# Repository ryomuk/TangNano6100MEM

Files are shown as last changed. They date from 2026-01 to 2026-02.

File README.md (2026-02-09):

# TangNano6100MEM
Memory systems and peripherals implemented on Tang Nano 20K for Intersil IM6100 PDP-8 Processor

This document is written mostly in Japanese, so please use machine translation if necessary.

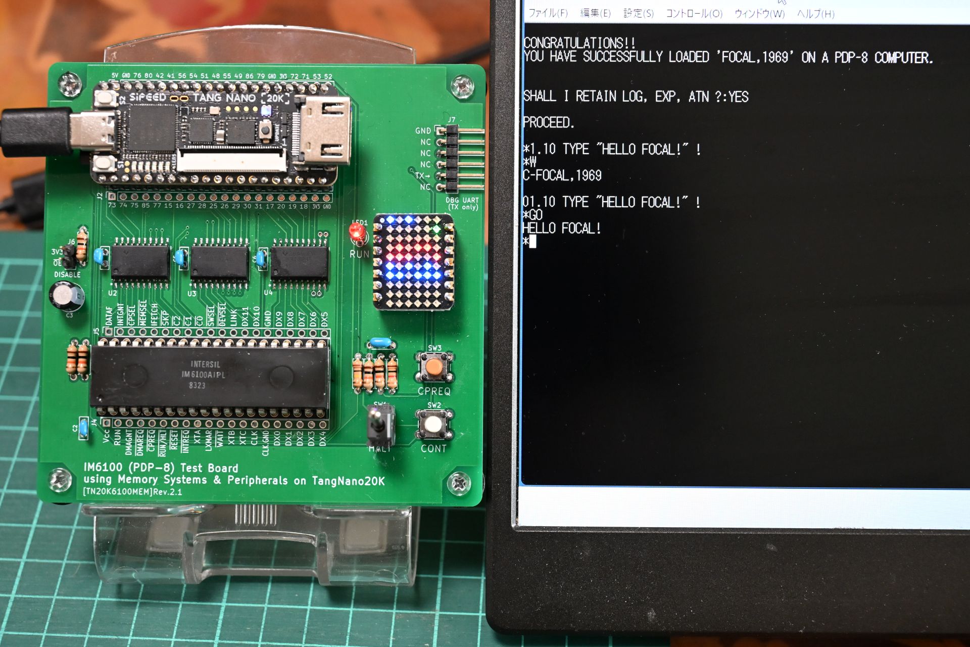
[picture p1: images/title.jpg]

# 概要
- PDP-8の命令セットを持つCPU「Intersil IM6100」のメモリシステムと周辺回路をFPGA(TangNano20K)上に実装する試みです．
- FPGAに実装するのはメモリ，UART, HDDなどの周辺装置の部分だけで，CPU自体は本物を使用します．ソフトウェアやFPGAによるシミュレータやエミュレータではなく，実物のCPUを動かします．
- "TangNano6100"だとTangNano上にIM6100を実装したみたいな名前になってしまうので，"MEM"を付けて"TangNano6100MEM"という名前になっています．
- モニタプログラムとして，Haruo Asano氏による[Universal Monitor](https://electrelic.com/electrelic/node/1317)IM6100版をControl Panel空間で動くように改変したものを搭載しました．MITライセンスだったので，使用した部分のソースを同梱しています．

## 最近の主な話題
- 2026/01/28: 初版公開
- 2026/02/01: version 20260201, 紙テープエミュレータ実装
- 2026/02/02: version 20260202, 割り込み関連のバグ修正
- 2026/02/02: CP空間のuniversal monitorにコンテキストの保存復帰を実装しました．
- 2026/02/06: version 20260206, 拡張メモリ関連の微修正
- 2026/02/06: OS/8のRK2, RK3を有効化する方法についてのドキュメントを追加．
  
## 主なファイル一覧
```
.
├── doc                      : 説明用文書
├── hdl                      : Gowin EDA用プロジェクト
│   ├── old                 : 旧版のバックアップ(あれば)
│   └── TangNano6100MEM_project: HDLソース一式
│       └── src
│            ├── dbglog.v   : debug log用モジュール
│            ├── mem.v      : メモリ初期データ(OS/8 bootloader)
│            ├── mem_cp.v   : CPメモリデータ(unimon)
│            ├── sdhd.v     : HDエミュレータモジュール
│            ├── sdtape.v   : 紙tapeエミュレータモジュール
│            ├── switch.v   : スイッチ用モジュール
│            ├── TangNano6100MEM_project.sdc : 時間制約(適当)
│            ├── tn20k.cst  :  物理制約(ピンアサイン)
│            ├── top.v      : メインプログラム
│            ├── uart.v     : uartモジュール
│            ├── ws2812.v   : WS2812モジュール
│            └── ws2812_matrix.v : WS2812 matrix用モジュール
├── images                   : 文書用画像ファイル
├── LICENSE
├── pcb
│   └── rev2.1 :  回路図，基板データ等(KiCAD 9用)
├── README.md   : このファイル
└── tools
    ├── papertape
    │   └── ptp2v.c    : 紙テープバイナリ変換用ソフト
    ├── sample          : bootやテスト用プログラム(unimonで書く用)
    └── unimon          : Universal Monitor
        ├── im6100      : IM6100 Control Panel版
        └── LICENSE.txt : 上記のライセンスファイル

```

各種説明は[doc/](./doc/)に項目に分けて記載しています．
- [更新履歴](doc/01_updatelog.md)
- [基板関連](doc/02_PCB.md)
- [FPGA関連](doc/03_FPGA.md)
- [インターフェース](doc/04_Interface.md)
- [SDメモリ](doc/05_SDmemory.md)
- [応用例](doc/06-0_applications.md)
  - [ベアメタル](doc/06-1_baremetal.md)
  - [紙テープソフト](doc/06-2_papertape.md)
  - [OS/8](doc/06-3_os8.md)
    - [RK2-3diskの有効化](doc/06-3_os8_reconfig.md)
- [デバッグツール](doc/07_debugtool.md)
- [関連情報・参考資料](doc/08_references.md)

## その他
以下，雑多な情報です．

### 動作状況
- 紙テープソフトやOS/8およびOS/8上で動く言語処理系などがある程度動作します．
- OS/8のBASICで簡単なプログラムを入力したりセーブ/ロードしたりできます．
  - STRTRK.BAやSNOOPY.BAが動きました．
- コントロールパネル空間でUniversal Monitorが動きます．

### 既知の問題
- ステップ実行後に戻ってくるとおかしくなることがある．
- ~~OS/8版のFOCALが動かない．おそらく割り込み関連の問題．~~ → やはり割り込みの問題でした．20260202版で修正して解決．
- ~~OS/8でDIR SYS: はできるが DIR RKA0: は止まる．~~ → PDP/8ハンドブックの誤植が原因でした．RK_DONEフラグを修正したら動くようになりました．
- ~~OS/8 BASICでSTRTRK.BAやSNOOPY.BAが動かない．~~ 動きました．

### 今後の予定，ToDo
- 紙テープイメージからOS/8のディスクイメージを作成．
  - → ある程度はできたのですが，CCL.SVがうまく作れなかったりEPICの動作が不安定なのであきらめました．
- 磁気テープドライブエミュレータ実装．(紙テープは実装済なので，必要でなければやらないかも)
  - → いろいろ面倒な仕様があったのであきらめました．

<!--
# 動画
- 未
-->

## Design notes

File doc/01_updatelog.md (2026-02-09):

# 更新ログ
- 2026/01/28: 初版公開
  - PCB rev2.1
  - HDL version 20260128
- 2026/01/29: HDLアップデート(version 20260129)
  - ステータスレジスタのフラグ(RK_DONE)修正
  - dbg_mode導入(SW2でクロック1000Hzにしてログ出力)
- 2026/02/01: HDLアップデート(version 20260201)
  - 紙テープエミュレータ実装
  - universal monitorにコマンド追加(Switch register, data field)
- 2026/02/02: HDLアップデート(version 20260202)
  - 割り込み時に拡張メモリのレジスタ(REG_IF, DF, IB)のクリアを追加
- 2026/02/02:
  - CP空間のuniversal monitorにコンテキストの保存復帰を実装しました．
- 2026/02/06:
  - CP空間ではJMP,JMS時にIF<=IBをしないように修正

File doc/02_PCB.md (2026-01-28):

# 基板 rev.2.1
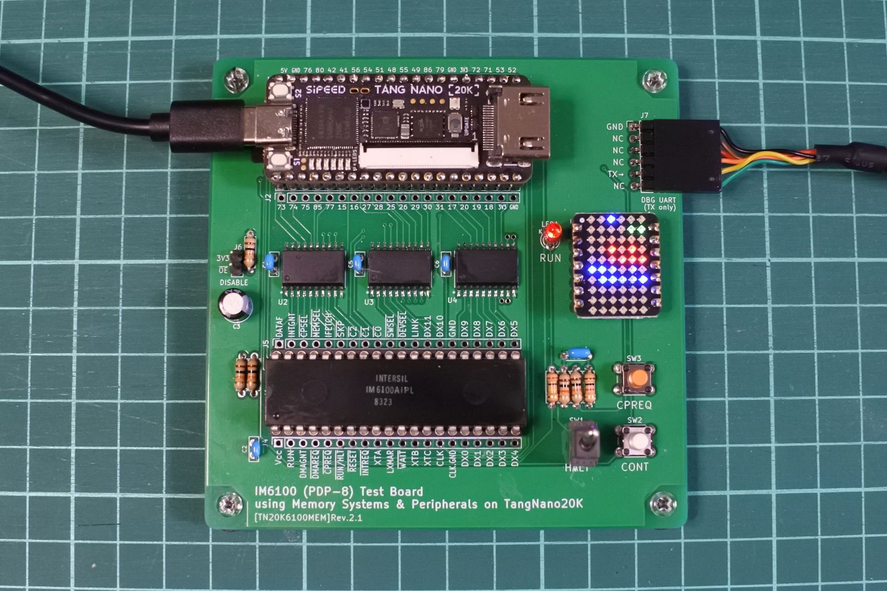
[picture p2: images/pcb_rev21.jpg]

#### BOM
|Reference |Value| Qty  |Memo |
|---|-----|---|-----|
|C1|1uF|1|||
|C2,C4,C5,C6|0.1uF|4||
|C3|47uF|1|||
|J1|01x20 pin socket|2|TangNano20K用|
|J2,J3,J4,J5|01x20 pin socket or header|4||実験用．無くても可．|
|J6|01x2 pin header|1|無くても可．|
|J7|01x6 pin header(L字)|1|デバッグUART用|
|LED1|LED|1| If=50μAぐらいで点灯するもの|
|R1,R2,R4,R5,R7|10k|5||
|R3|47k|1||
|R6|1k|1||
|SW1|トグルSW|1||
|SW2, SW3|タクトSW|1||
|U1|IM6100A|1|40P DIP 600mil socket|
|U2,U3,U4|SN74CB3T3245DWR(DWでも可)|3|SOIC-20．サイズに注意|
|U5|WS2812B 6x10 matrix|1|Seeed Studio XIAO用 6×10 RGBマトリクス|

#### パーツに関する補足や注意事項
- SN74CB3T3245はパッケージサイズに注意．SOIC-20はDWかDWRです．PWやPWRではありません．
- LEDは47KΩつけたけでCPUに直結しています．If=70μAぐらいで点灯するLEDを使って下さい．とりあえず，下記が使えることを確認しました．
  - OSR5PA3133A-1MA https://akizukidenshi.com/catalog/g/g116908/ 最初これを使っていたのですが販売終了でした．
  - OSR5JA3Z74A https://akizukidenshi.com/catalog/g/g111577/
  - OSR5JA7WA1B https://akizukidenshi.com/catalog/g/g114260/

#### 主なパーツの入手先
|parts |store|
|---|-----|
|Tang Nano 20K| 秋月, Sipeed Store(Aliexpress)|
|SN74CB3T3245DWR|マルツ, Mouser, Digikey|
|IM6100A|eBay|
|Seeed Studio XIAO用 6×10 RGBマトリクス|マルツ, Switch Science|
|その他の部品| 秋月, マルツ，共立|

#### レベル変換について
- 信号のインターフェース部分にはバススイッチSN74CB3T3245を使用しています．
  - CPU→FPGAの信号レベルは5Vから3.3Vに変換されます．
  - FPGA→CPUの信号レベルは3.3Vのままです．
- IM6100のデータシートによると，TTL compatibleとあるので3.3Vレベルの信号を入力に使えるはずなのですが，一方でVih=70%*Vcc との記載もあり，若干不安だったのですがとりあえず今の実装で動いているので大丈夫なようです．

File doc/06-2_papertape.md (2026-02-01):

# paper tape software
- SDメモリで動作する紙テープエミュレータを実装しました。
- インターネット上のPDP8関連のアーカイブから入手できる紙テープのイメージを全く加工せずにddで書き込むだけでロードと起動ができることを目標にしました．
- tangnanoのSW1で8個のtape imageから1つ選択します．
- 0が1024個続くとEnd of Tapeと判断し読み込みは停止します．状態はMatrix LEDに表示されます．(LEDの位置はtop.v参照．)
- モニタからGで起動したときや読み込みの途中でEOTでないのにHALTで止まったらCONTを押して継続します．

## boot loader
- RIM loader(開始アドレス=7756)をいちいちモニタで書き込むのは面倒なので，メモリ上に置いてあります．(当時はパネルスイッチでパチパチ入力していたようですが．)
- ついでにbinary loader(開始アドレス=7701)も置いておきましたが，ちょっとチートな気もします．binary loader自身もちゃんとRIM loaderで読む方が本格的な気分になれます．(mem.vのdefine文で無効にできます．)
- メモリの初期値は今後変わるかもしれないので，最新の情報はmem.vを確認して下さい．

## 動作例
### 4k BASIC (edusystem 10)
- http://www.bitsavers.org/bits/DEC/pdp8/papertapeImages/basic/edusystem-10/
- ファイル名: dec-08-ed10a-a-pb-new.ptp
- 最初にbinary loader，続いてプログラムが格納されている．
- RIMローダーを起動するだけで自動的に実行された．
```
Universal Monitor IM6100 (Control Panel)
7777
] G7756
# HALTで止まっていたらCONTボタンを押す

SELECT THE SMALLEST SET OF FUNCTIONS NEEDED FROM THE FOLLOWING CHOICES
ATN         ! !X! ! ! ! ! !
LOG+EXP     ! !X!X! ! ! ! !
SIN+COS+TAN ! !X!X!X! ! ! !
DEF(FN)     ! !X!X!X!X! ! !
SQR         ! !X!X!X!X!X! !
RND         ! !X!X!X!X!X!X!

OPTION       A B C D E F G

TYPE OPTION LETTER?G
DO SUBSCRIPTS START AT 0 OR 1?0
READY.
```

### 8k BASIC
- https://computermuseum.informatik.uni-stuttgart.de/ftp/dec/papertapes/basic-8/
- ファイル名: BASIC8.BN
- 上記リンクにソースとマニュアルもあり．
- binary loaderでロード
- 開始アドレス=1000
```
Universal Monitor IM6100 (Control Panel)
7777
] G7701
# HALTで止まったらCONTを押す．
# End of TapeになったらCPREQでモニタを起動
Universal Monitor IM6100 (Control Panel)
7670
] G1000

READY.

PRINT "HELLO 8K BASIC"
HELLO 8K BASIC
```

### FOCAL
- http://www.bitsavers.org/bits/DEC/pdp8/From_pdp8.hachti.de/hachti-pdp8-tapes/
- ファイル名: DEC-08-AJAE-PB.bin
- 開始アドレス=0200
- binary loaderで起動します．
- 末尾のゴミ(後述)のせいでDFが1になったり，244番地が書き替えられてたりするので手動で修正します．
```
Universal Monitor IM6100 (Control Panel)
7777
] G7701
# 途中で5〜6回くらい止まるのでCONTで読込を継続．
# End of TapeになったらCPREQでモニタに戻ってDFと244番地を修正して起動．

Universal Monitor IM6100 (Control Panel)
7671
] F0
0000
] S244
0244 : 3044 4554
0245 : 1124 .
] G200

CONGRATULATIONS!!
YOU HAVE SUCCESSFULLY LOADED 'FOCAL,1969' ON A PDP-8 COMPUTER.

SHALL I RETAIN LOG, EXP, ATN ?:YES

PROCEED.

*1.10 TYPE "HELLO FOCAL!" !
*W
C-FOCAL,1969

01.10 TYPE "HELLO FOCAL!" !
*GO
HELLO FOCAL!
*

```
末尾のこのあたりのデータが悪さをしているようです．削除してもいいのですが，上記修正で直ったのでとりあえずそれで済ませました．
```
# /usr/bin/od -t o1 DEC-08-AJAE-PB.bin | less
0017600 000 000 000 000 000 000 000 000 000 000 000 252 125 252 056 073
0017620 052 056 000 000 000 000 000 000 000 000 000 000 000 000 000 000
0017640 000 000 000 000 000 000 000 000 000 000 000 000 000 000 000 000
*
0020100 000 000 000 000 000 000 102 044 030 044 102 201 102 044 030 044
0020120 102 201 102 044 030 044 102 201 314 000 000
```

### LISP
- http://www.bitsavers.org/bits/DEC/pdp8/papertapeImages/set1/
- ファイル名: DECUS_8_102A_LISP.BIN
- 開始アドレス=3000 (自動実行)
- 自動実行なので，Self-Starting Binary Loader を試してみました．
  - https://deramp.com/downloads/mfe_archive/011-Digital%20Equipment%20Corporation/01%20DEC%20PDP-8%20Family%20Software/02%20Paper%20Tape%20Utilities/DEC-8E-XBINA%20Bina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
  - ファイル名: DEC_8E_XBINA_A_PB.BIN

```
# G7756でRIM Loaderを起動してSS Bin Loaderを読む．
Universal Monitor IM6100 (Control Panel)
7777
] G7756
# EOTが点灯して止まったら，SW1でイメージファイルをLISPに変更してCONT
# 再度EOTが点灯するまで5回くらいCONT
# EOTの点灯と同時にLISPが起動する．(起動メッセージは無い)

()()
 NIL
CAR((A B C))
 A

```

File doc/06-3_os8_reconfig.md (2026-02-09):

## RK2, RK3 diskの有効化

- os8.rk05は，RKのunitが2台((RKA0, RKB0)と(RKA1, RKB1))の設定でBUILDされている
ようなので設定を変更します．手順は下記の通り．

- モニタからOS/8を起動します．
```
Universal Monitor IM6100 (Control Panel)
07777
AC=0000 FLG,IF,DF=0000 SR=0000
] G23
```
- 登録されているデバイス(リソース)を確認します
```
.RES /L

1109 FREE BLOCKS

 NAME TYPE USER
 SYS  RK8E
 DSK  RK8E
 PTP  PTP 
 PTR  PTR 
 RXA0 RX8E
 RXA1 RX8E
 RKA0 RK8E
 RKB0 RK8E
 RKA1 RK8E
 RKB1 RK8E
 TTY  TTY 
 LPT  LPTR
 RF   RF08
 DTA0 TC08
 DTA1 TC08

OS/8 V3Q
```
- まだRKB3:は無いので下記はエラーになります．
```
.DIR RKB3:
RKB3 DOES NOT EXIST
```
- BUILDを起動します．
```
.R BUILD
```
- 登録されているデバイスを確認します．有効なデバイスにはアスタリスクが付いています．RKA2-3, RKB2-3はハンドラはあるようですが有効化されていません．
```
$PR

PT8E: *PTP  *PTR  
RX01: *RXA0 *RXA1 
RK8E: *SYS   RKA0  RKB0 
RK05: *RKA0 *RKB0 *RKA1 *RKB1  RKA2  RKB2  RKA3  RKB3 
KL8E: *TTY  
LS8E: *LPT  
RF  : *RF    NULL 
TC  : *DTA0 *DTA1  DTA2  DTA3  DTA4  DTA5  DTA6  DTA7 
```
- 全部で16個までしか登録できないので，いらないデバイスを削除します．
```
$UNLOAD RX01

$UNLOAD RF

$UNLOAD TC
```
- RK2(RKA2, RKB2)とRK3(RKB2, RKB3)を有効化します．
```
$IN RK05:RKA2-3,RKB2-3
```
- 確認します．
```
$PR

PT8E: *PTP  *PTR  
RK8E: *SYS   RKA0  RKB0 
RK05: *RKA0 *RKB0 *RKA1 *RKB1 *RKA2 *RKB2 *RKA3 *RKB3 
KL8E: *TTY  
LS8E: *LPT  
```
- BOOTします．
```
$BOOT
SYS BUILT
```
- リソースを確認します．
```
.RES /L

1109 FREE BLOCKS

 NAME TYPE USER
 SYS  RK8E
 DSK  RK8E
 PTP  PTP 
 PTR  PTR 
 RKA0 RK8E
 RKB0 RK8E
 RKA1 RK8E
 RKB1 RK8E
 RKA2 RK8E
 RKB2 RK8E
 RKA3 RK8E
 RKB3 RK8E
 TTY  TTY 
 LPT  LPTR

OS/8 V3Q
```
-  ディスクアクセスのログによると，BOOT時にSYS:上のファイルが書き換えられているようでした．rebootして確認します．
```
.
Universal Monitor IM6100 (Control Panel)
01210
AC=0000 FLG,IF,DF=4000 SR=0000
] S23
0023 : 0200 6007
0024 : 1200 6744
0025 : 0211 1032
0026 : 7607 6746
0027 : 5372 6743
0030 : 6203 1032
0031 : 0321 5031
0032 : 1630 0000
0033 : 0402 .
] G23

.RES /L

1109 FREE BLOCKS

 NAME TYPE USER
 SYS  RK8E
 DSK  RK8E
 PTP  PTP 
 PTR  PTR 
 RKA0 RK8E
 RKB0 RK8E
 RKA1 RK8E
 RKB1 RK8E
 RKA2 RK8E
 RKB2 RK8E
 RKA3 RK8E
 RKB3 RK8E
 TTY  TTY 
 LPT  LPTR

OS/8 V3Q
```
- RKB3:が読めるようになりました．
```
.DIR RKB3:

ABSLDR.SV   6           RL2SY .BH   2           DHLAAB.DG  13
CCL   .SV  31           RL20  .BH   2           DHTAAC.DG  17
DIRECT.SV   7           RL21  .BH   2           DHTABC.DG  13
PIP   .SV  11           RL2E  .BH   2           DHTMAB.DG  17
FOTP  .SV   8           ROMMSY.BH   1           DHTMBB.DG  17
SET   .SV  20           RXSY1 .BH   2           DHTMCA.DG  10
FUTIL .SV  27           RXSY2 .BH   2           DHTMDB.DG  15
BATCH .SV  10           RXNS  .BH   2           DHTMEB.DG  15
HELP  .SV   8           RXBSY1.BH   2           DHTMFC.DG  11
FRTS  .SV  26           RXBSY2.BH   2           DHTSAB.DG  17
RKBOOT.SV   2           RXBNS .BH   2           DHTSBB.DG  17
BASIC .SV  11           RX28C .BH   2           DHTSCB.DG  15
BLOAD .SV  10           RX78C .BH   2           DHTSDB.DG  13
BCOMP .SV  26           TC08SY.BH   1           DHTSEA.DG  10
BRTS  .SV  25           TC08NS.BH   2           DHTSFA.DG   3
CHESS .SV  28           TD8ESY.BH   2           DHVCAA.DG  13
ADVENT.SV 129           TD8EA .BH   2           DHVTAB.DG  11
BASIC .UF   2           TD8EB .BH   2           DHVTBA.DG   4
BASIC .OV  16           TM8E  .BH   2           DHVTDA.DG  16
RK8EA .SY  50           VXSY  .BH   1           DIADFA.DG  11
RK8EB .SY  50           VXNS  .BH   1           DIAFBA.DG  17
RKS8EA.SY  50           RECOVR.BI   2           DIDBAA.DG   7
RKS8EB.SY  50           ADVENT.DA 145           DIDFAC.DG   7
HELP  .HL  67           ADVENT.LD 143           DIDFBA.DG  10
GAMES .HL  63           ADVENT.TX 200           DIDFCA.DG  17
ASR33 .BH   1           BANNER.BA  23           DILTCA.DG   6
BAT   .BH   1           FUTIL .TX 316           DILTDA.DG  10
CR8E  .BH   2           DECX8 .TX  64           DILVAA.DG  10
CS    .BH   2           OS8   .TX  58           DIRTAB.DG  14
DF32SY.BH   1           DIAG  .TX  88           DITCBA.DG  11
DF32NS.BH   1           TITLE .TX   7           DITCCA.DG   9
DUMP  .BH   2           TYPSET.DG  10           DITCDA.DG  15
KL8E  .BH   2           SHELLY.DG   4           DIUDAC.DG  17
LINCSY.BH   1           AUVAAA.DG  16           DIVTBA.DG   8
LINCNS.BH   2           AUVBAB.DG  16           DIVTCA.DG  11
LPSV  .BH   1           AUVCAA.DG   6           DJADAC.DG  16
LQP   .BH   2           AUVDAB.DG   9           DJVKAB.DG  15
MODLQP.BH   2           AUVEAD.DG   8           DIRECT.TS   6
PT8E  .BH   1           DGV5AB.DG  13           RKS8ES.PA  37
RF08SY.BH   1           DHADAA.DG  11           RKSFMT.LC   6
RF08NS.BH   1           DHCMAA.DG  10           RKSREL.LC   9
RK08SY.BH   1           DHCRAA.DG  10           RKSLES.LC  16
RK08NS.BH   1           DHDHAA.DG   7           RKSWCT.LC   8
RK8EA .BH   1           DHDHCA.DG   2           RKSCTL.LC  16
RK8EB .BH   1           DHDKAA.DG  15           RKCOPY.LC   5
RK8ENS.BH   2           DHDPAD.DG  18           JDAY8E.SY  50
RKS8EA.BH   1           DHDRAB.DG  11           RKSFMT.DG   6
RKS8EB.BH   1           DHDRHA.DG  11           RKSWCT.DG   8
RKS8NS.BH   2           DHICAA.DG  21           RKSCTL.DG  16
RLSY  .BH   2           DHKGAB.DG  14           RKSREL.DG   9
RL0   .BH   2           DHKLBB.DG  13           RKSLES.DG  16
RL1   .BH   2           DHKLCD.DG   8           RKCOPY.DG   5
RLC   .BH   2           

 157 FILES IN 2762 BLOCKS -  430 FREE BLOCKS

.

```

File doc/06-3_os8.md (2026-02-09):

## OS/8
- 下記のdisk imageで起動できました．
- [CPLDP-8 by omiokone](https://omiokone.sakura.ne.jp/cpldp8/index.htm) cpld83C.zip中にある os8.rk05
- [pdp8online:PDP-8 File list for os8](https://www.pdp8online.com/images/images/os8.shtml) にある，advent.rk05 , diag-games-kermit.rk05, diagpack2.rk05
を8192ブロックごとに並べたファイルsd.dskを作り，ddでSDメモリの先頭ブロックから書き込みます．
```
dd if=os8.rk05               of=sd.dsk bs=512
dd if=advent.rk05            of=sd.dsk bs=512 seek=8192  conv=notrunc
dd if=diag-games-kermit.rk05 of=sd.dsk bs=512 seek=16384 conv=notrunc
dd if=diagpack2.rk05         of=sd.dsk bs=512 seek=24576 conv=notrunc

dd if=sd.dsk of=/dev/xxx
```
/dev/xxx は/dev/sdbなど，生のsdメモリの場所です．ちゃんと調べて間違えないように書き込んで下さい．間違えるとPCのディスクを破壊する可能性があります．

### 起動方法
- SDメモリをTangConsoleのスロットにセットします．
- コントロールパネルのUniversal Monitorを起動します．

### 使用例
下記のようにメインメモリ空間にOS/8のboot loaderを書いて実行することによりbootできます．

```
Universal Monitor IM6100 (Control Panel)
7777
] S23
0023 : 0005 6007
0024 : 3602 6744
0025 : 0000 1032
0026 : 3724 6746
0027 : 0000 6743
0030 : 7500 1032
0031 : 0000 5031
0032 : 0001 0000
0033 : 0000 .
] G23

.DIR

ABSLDR.SV   5           BASIC .FF   4           PAGE8 .SV  49
BATCH .SV  10           BASIC .SF   4           ICE   .SV  26
...(略)...
LOADER.SV  12           LISP  .SV  18           HOGE  .BA   1
SABR  .SV  24           PASCAL.SV  51           BASIC .WS   1
BASIC .AF   4

  94 FILES IN 2085 BLOCKS - 1107 FREE BLOCKS

.
```

- os8.rk05は，RKのunitが2台((RKA0, RKB0)と(RKA1, RKB1))の設定でBUILDされているようなので設定を変更します．手順は[06-3_os8_reconfig](./06-3_os8_reconfig.md)参照．

- BASICで簡単なプログラムを入力したりセーブ/ロードしたりできました．

```
.R BASIC
NEW OR OLD--NEW
FILE NAME--AAA

READY
10 PRINT "HELLO OS/8 BASIC"
20 END
LIST

AAA     BA    5B

10 PRINT "HELLO OS/8 BASIC"
20 END

READY
RUN

AAA     BA    5B

HELLO OS/8 BASIC

READY
SAVE

READY
BYE

.R BASIC
NEW OR OLD--OLD
FILE NAME--AAA

READY
LIST

AAA     BA    5B

10 PRINT "HELLO OS/8 BASIC"
20 END

READY
```

- STRTRK.BAも動きました．
```
.BASIC
NEW OR OLD--OLD
FILE NAME--STRTRK

READY
RUN

STRTRK  BA    5B

STAR TREK SPACE SIMULATOR

DO YOU NEED INSTRUCTIONS?N

COMBAT AREA   CONDITION RED
  SHIELDS DANGEROUSLY LOW

------------------------

    *                        STARDATE      3400
                             CONDITION     RED
         +++                 ENERGY        3000
                             TORPEDOES     15
                      *      SHIELDS       0
      +++                    KLINGONS      21
 *     *  *          <*>
------------------------
COMMAND?
```

- FOCALも動きました．
```
.R PFOCAL

DO YOU WANT THE STANDARD FEATURES OF PS/8 FOCAL, 1971?  NO

RETRY OR TYPE HELP:  HELP

ANSWER BY TYPING THE CODES TO RETAIN THE FEATURES:

1  SIN & COS
2  SIN, COS, LOG, EXP & ATN
3  EXTENDED PRECISION
4  FILE COMMANDS
5  LEADING SPACE IN 'TYPE'
6  '=' IN 'TYPE' (OPTION 5 DISABLES THIS OPTION)
7  ':' IN 'ASK'
8  '&' IN POWERS-OF-TEN NOTATION
9  RETAINS FEATURES 2,3,4
0  RETAINS NONE OF LISTED FEATURES

YES  RETAINS STANDARD FEATURES 2,3,4,5
RUBOUT DELETES PRECEEDING CHARACTER
'_' OR CTRL/U KILLS LINE

DO YOU WANT THE STANDARD FEATURES OF PS/8 FOCAL, 1971?  0

PROCEED.

*1.10 TYPE "HELLO OS/8 FOCAL!" !
*W
C-PS/8 FOCAL, 1971

01.10 TYPE "HELLO OS/8 FOCAL!" !
*GO
HELLO OS/8 FOCAL!
*
```

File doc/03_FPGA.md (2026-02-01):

# FPGA関連
## ビルド時の注意点
### Gowin FPGA Designerの設定について
- Configulationはimpl/の*.config.jsonに保存されているようなので，特に何もする必要は無いはずですが，もしエラーが出た場合は、Configuration->Dual-Purpose Pin で"Use SSPI as regular IO"をチェックして下さい．
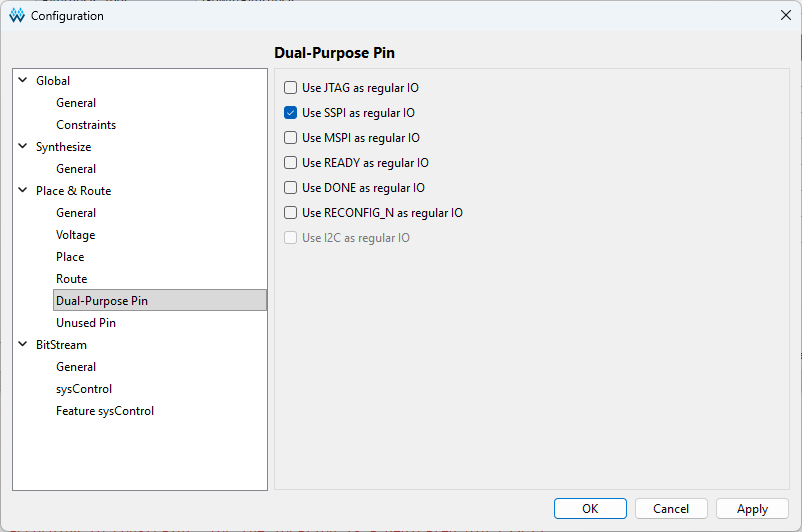
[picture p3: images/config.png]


### warning
- 下記のwarningが出ますが，対処方法がいまいちわからないので放置しています．
```
WARN  (PR1014) : Generic routing resource will be used to clock signal 'sys_clk27_d' by the specified constraint. And then it may lead to the excessive delay or skew
```

### program
- UARTのポートが複数あるので，Gowin programmerでは適切なポートを選択する必要があります．
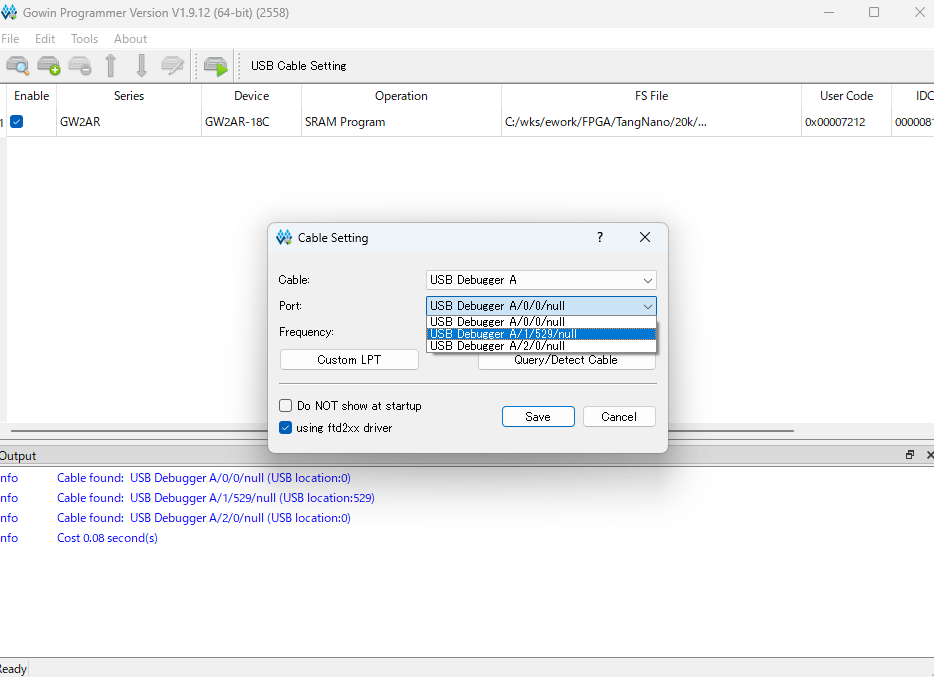
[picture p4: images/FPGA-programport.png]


# FPGAに実装した機能
- TTYコンソール入出力用UART
- 32MW メモリシステム(拡張メモリ)
- 4KW コントロールパネルメモリ
- 割り込み
- RK8E/RK05 ハードディスク (sdメモリによるエミュレーション)
- デバッグ機能(デバッグログ，matrix LED, debug用HALT, CP空間モニタ)

## デバッグ用機能
- 6x10 matrixにいろいろな情報が出力されます．詳細はソースtop.vを参照．
- DBG_UARTに下記の情報が出力されます．詳細はソースtop.vを参照．
  - 一番左は1msタイマーの値．
  - RKディスクアクセス時のコマンド，ディスクアドレス，メモリアドレス等
  - ステップ実行時の命令，アドレス等
- CPREQ ボタンを押すとControl Panel空間でUniversal Monitorが起動します．

## CPUのクロックについて
- CPUのクロックはTangNanoの27MHzのsys_clkを分周して作っています．PLLを使えばもっと細かい値の制御ができますが，IPはなるべく使わない方針なので．
- 分周比が奇数のときはduty比が50%より若干大きくなります．50%にしたら5.4MHzで動かなくなったので，50%にするためのコードはコメントアウトしてます．なので分周比は偶数の方が安全かと思います．
- IM6100AはVcc=10Vで8MHzというスペックのようですが，5Vでも5.4MHzであれば動き，個体によっては6.75MHzで動作するものもありました．ただ，4.5MHzでも時々誤動作することがあったので，余裕をみて3.375MHzにしています．
- もっと速いクロックを試す場合や，6100無印, -1, C等を使う場合には必要に応じてtop.vのCPU_CLK_RATIOを変更して下さい．

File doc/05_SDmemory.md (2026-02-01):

## SDメモリ
- RKディスクエミュレータと紙テープエミュレータ用のディスクイメージをSDメモリに書き込み，TangNano 20KのSDメモリスロットに入れます．
- fat等のファイルシステムは持たず，ddでブロックの先頭から生で使用します．

## メモリイメージの構成
- まだ開発途上なので変更する可能性があります．
- 基本的にはtop.vのコメントに書いてあります．下記に再掲します．
- SW1で先頭ブロックをシフトして紙テープイメージを選択できるようになっています．

```
// RK Disk
// 256 word x 16 sector x 203 cyl(track) x 2 surface
// 6496 * 256word(512byte) block (1,662,976 word)
//
// 1 block = 256word = 512B = 01000B
// SD memory block
// each RK05 disk image uses first 6496 block in 8192 block.
// (DRIVE_BLOCK_SIZE = 8192 (= 16 * 2 * 256))
//        0- 8191: RK0 (00000000)
//     8192-16383: RK1 (00020000)
//    16384-24575: RK2 (00040000)
//    24576-32767: RK3 (00060000)
//    32768-33791: TP0 (00100000)
//    33792-34815: TP1 (00102000)
//    34816-35839: TP2 (00104000)
//    35840-36863: TP3 (00106000)
//    36864-37887: TP4 (00110000)
//    37888-38911: TP5 (00112000)
//    38912-39935: TP6 (00114000)
//    39936-40959: TP7 (00116000)
//
```

複数のディスクイメージをまとめてsdメモリ用のイメージsd.dskを作る例．

```
# disk images
dd if=os8.rk05                  of=sd.dsk bs=512
dd if=diag-games-kermit.rk05    of=sd.dsk bs=512 seek=8192  conv=notrunc
dd if=advent.rk05               of=sd.dsk bs=512 seek=16384 conv=notrunc
dd if=sample.rk05               of=sd.dsk bs=512 seek=24576 conv=notrunc
# tape images
dd if=dec-08-lbaa-pm            of=sd.dsk bs=512 seek=32768 conv=notrunc
dd if=DEC_8E_XBINA_A_PB.BIN     of=sd.dsk bs=512 seek=33792 conv=notrunc
dd if=dec-08-ed10a-a-pb-new.ptp of=sd.dsk bs=512 seek=34816 conv=notrunc
dd if=BASIC8.BN                 of=sd.dsk bs=512 seek=35840 conv=notrunc
dd if=DEC-08-AJAE-PB.bin        of=sd.dsk bs=512 seek=36864 conv=notrunc
dd if=DECUS_8_102A_LISP.BIN     of=sd.dsk bs=512 seek=37888 conv=notrunc
```

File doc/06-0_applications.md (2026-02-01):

# 応用例

## [ベアメタル](06-1_baremetal.md)
## [Paper Tape Software](06-2_papertape.md)
## [OS/8](06-3_os8.md)

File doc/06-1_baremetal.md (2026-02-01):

# ベアメタル

下記のような手段でプログラムをメモリに格納し，ベアメタルで動作させることができます．
- universal monitor(使い方は[debugtool.md](07_debugtool.md)参照)でメモリに書く
- アセンブラで作成したバイナリデータやmem.vに変換してビルド
- 紙テープイメージから作ったメモリデータをmem.vに変換してビルド

### Universal Monitorでメモリに書いて実行
```
# CPREQボタンを押してモニタを起動
Universal Monitor IM6100 (Control Panel)
7777
] S200
0200 : 0000 6032
0201 : 0000 6031
0202 : 0000 5201
0203 : 0000 6036
0204 : 0000 6046
0205 : 0000 6041
0206 : 0000 5205
0207 : 0000 5200
0210 : 0000 .
] G200
# HALTで止まっていたらCONTボタンを押す
# キー入力がechoされる
Hello!
Keyboard echo test
```

### アセンブラで作ったバイナリからメモリデータへの変換
- [tools/unimon/im6100/bin2v.pl](../tools/unimon/im6100/bin2v.pl)
を参考にして下さい．コントロールパネル空間用になっているので，適宜変更して下さい．

### 紙テープイメージからメモリデータへの変換
- 紙テープエミュレータを実装する前は，紙テープのimageをFPGAの初期メモリデータmem.vに変換して再ビルドするという手順で紙テープソフトを実行しました．変換用のプログラムはこれ→[tools/papertape/ptp2v.c](../tools/papertape/ptp2v.c) 
- テープの末尾のゴミを手作業で修正する必要があります．(それほど多くはない)
- 起動アドレスを7776番地に書き込みます．(CPのunimonからGで実行しても可．)
- リセット時に7777でHALTするので，CONTボタンを押して実行．

#### FOCAL
```
$ ptp2v DEC-08-AJAE-PB.bin > mem.v
開始アドレスを修正 (そのままにしてCPのunimonからG200でも可)
mem['o7776]='o7777; // set start address here
↓
mem['o7776]='o0200;
```
ビルドしてFPGAに書き込んで起動．
```
CONGRATULATIONS!!
YOU HAVE SUCCESSFULLY LOADED 'FOCAL,1969' ON A PDP-8 COMPUTER.

SHALL I RETAIN LOG, EXP, ATN ?:YES

PROCEED.

*
```

#### 4K BASIC
```
$ ptp2v dec-08-ed10a-a-pb-new.ptp > mem.v
開始アドレスを修正
mem['o7776]='o7777; // set start address here
↓
mem['o7776]='o0200;
```
ビルドしてFPGAに書き込んで起動．
```
SELECT THE SMALLEST SET OF FUNCTIONS NEEDED FROM THE FOLLOWING CHOICES
ATN         ! !X! ! ! ! ! !
LOG+EXP     ! !X!X! ! ! ! !
SIN+COS+TAN ! !X!X!X! ! ! !
DEF(FN)     ! !X!X!X!X! ! !
SQR         ! !X!X!X!X!X! !
RND         ! !X!X!X!X!X!X!

OPTION       A B C D E F G

TYPE OPTION LETTER?G
DO SUBSCRIPTS START AT 0 OR 1?0
READY.
```

#### 8K BASIC
```
$ ptp2v BASIC8.BN > mem.v
開始アドレスを修正
mem['o7776]='o7777; // set start address here
↓
mem['o7776]='o1000;
```
ビルドしてFPGAに書き込んで起動．
```

READY.
```

#### LISP
```
$ ptp2v DECUS_8_102A_LISP.BIN > mem.v
ゴミを削除
mem['o3000]='o7407; ← これを消す．(開始アドレスなので，ちゃんと変換できてないだけ本来はゴミではない)
開始アドレスを修正
mem['o7776]='o7777; // set start address here
↓
mem['o7776]='o3000;
```
ビルドしてFPGAに書き込んで起動．
```
CAR((A B C))
 A

CDR((A B C))
 (B C)

CONS(A (B C D))
 (A B C D)

DEFINE (((FIB (LAMBDA (N)
         (COND ((EQUAL N 0) 0)
               ((EQUAL N 1) 1)
               (T (PLUS (FIB (MINUS N 1)) (FIB (MINUS N 2))))))
)))
 (FIB(LAMBDA(N)(COND((EQUAL N 0)0)((EQUAL N 1)1)(T(PLUS(FIB(
MINUS N 1))(FIB(MINUS N 2)))))))

FIB(10)
 55
```

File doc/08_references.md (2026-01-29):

# 関連情報
## 開発環境
- Tang Console 138K Device B (Device Cについては[doc/03_FPGA](doc/03_FPGA.md)参照．)
- Windows 11
  - [KiCAD](https://www.kicad.org/) 9.0.6
  - [GOWIN](https://www.gowinsemi.com/) FPGA Designer V1.9.12(64-bit)
  - VMware Workstation 17 Player
    - Ubuntu 22.04.4
      - dd
      - [simh](http://simh.trailing-edge.com/)
  - [TeraTerm](https://teratermproject.github.io/)
  - [Macro Assembler AS (ASL)](http://john.ccac.rwth-aachen.de:8000/as/)

## 各種リンク
### PDP-8関連
- [The Digital Equipment Corporation PDP-8 by Douglas W. Jones](https://homepage.cs.uiowa.edu/~dwjones/pdp8/)
- [PDP-8 Stuff](https://so-much-stuff.com/pdp8/index.php)
- [Online PDP-8 Home Page](https://www.pdp8online.com/)
- [Philipp Hachtmann's PDP8 website](http://pdp8.hachti.de/)

### IM6100関連
- [INTERSIL IM6100 CMOS 12 BIT MICROPROCESSOR](http://www.bitsavers.org/components/intersil/IM6100/Intersil_IM6100_12-Bit_CMOS_Microprocessor.pdf)
- [Intercept Prototyping System from Intersil Hardware Manual](http://www.bitsavers.org/components/intersil/IM6100/InterceptHW.pdf)
- [Intercept I and II Development System Users Manual](http://www.bitsavers.org/components/intersil/IM6100/Intercept_I_and_II_Development_System_Users_Manual.pdf)
- [Intercept JR. Tutorial System from Intersil Owner's Handbook](http://www.bitsavers.org/components/intersil/IM6100/Intercept_Jr_Tutorial_System_Owners_Handbook_197611.pdf)
- [IM6100 by nkomatsu](http://www.st.rim.or.jp/~nkomatsu/miscproc/IM6100.html): IM6100に関する詳しい日本語解説．データシートを読む助けになりました．

### 各種ソフトウェアのイメージデータの入手元
- [pdp8online:PDP-8 Archive](https://www.pdp8online.com/images/index.shtml): "os8"にrk05のイメージがいくつかあり
- [dbit.com](http://www.dbit.com/pub/pdp8/)
- [CPLDP-8](https://omiokone.sakura.ne.jp/cpldp8/index.htm): cpld83C.zip中にos8.rk05 あり
- [bitsavers:DEC/pdp8/](http://www.bitsavers.org/bits/DEC/pdp8/)
- [PDP-8 Stuff:software](https://so-much-stuff.com/pdp8/software/software.php)
- [DERAMP.COM](https://deramp.com/downloads/mfe_archive/011-Digital%20Equipment%20Corporation/)

### ハードウェア製作事例等
- [CPLDP-8 version 3 MAXIIでミニコンピュータをつくる by omiokone](https://omiokone.sakura.ne.jp/cpldp8/index.htm)
- [SBC6120 by Spare Time Gizmos](http://sparetimegizmos.com/Hardware/SBC6120-2.htm)
- [6120 Computer Projects](https://hb9aik.ch/computer/SBC6120.htm)
- [HD1-6120ボード（ハードウェア編）by Electrelic](https://electrelic.com/electrelic/node/1442)
- [PDP-8_IM6100 by nosuz](https://github.com/nosuz/PDP-8_IM6100)

## 開発環境関連
- [SimH (History Simulator)](http://simh.trailing-edge.com/)
- [Raymii.org: Running Adventure on the DEC PDP-8 with SIMH](https://raymii.org/s/articles/Running_ADVENT-on-the-PDP-8-with-SIMH.html)
- [Universal Monitor](https://electrelic.com/electrelic/node/1317)
- [Macro Assembler AS](http://john.ccac.rwth-aachen.de:8000/as/)

<!--
## 関連記事
## その他のIM61000関連のプロジェクト
-->

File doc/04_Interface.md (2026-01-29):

# インターフェース
## Tang NanoのUSB端子
- 5V電源の供給，端末ソフトとの通信に使用

## Tang Nanoのスイッチ
- SW1: ディスクイメージの選択に使用．(top.vの USER_drivesel 参照．)
- SW2: dbg_modeのトグル．([07_debugtool.md](./07_debugtool.md)参照
- SW1, SW2の同時押しでCPUをRESET (top.vの reset_sw)
これらのスイッチの用途は今後変更する可能性が高いです．

## 基板のスイッチと端子
- SW1(HALT): 下に倒すと1命令毎にHALTし，ステップ実行になります．
- SW2(CONT): 押すとRUN_HLT_nをLにし，RUN/HLT状態を切りかえます．(厳密にはRUN_HLT_nの正エッジで切りかわる．)
 - ** IM6100はリセット時にPC=7777でHALTするので，1回押してRUNにします．**
 - ステップ実行モード以外のときに長押しするとRESET_nをL(enable)にし，CPUをリセットします．
 - ステップ実行モードのときクリックすると1命令実行，長押しすると連射が有効になり，30命令/秒で実行します．
- SW3(CPREQ): CPREQ_nをL(enable)にし，CP空間で動くプログラム(universal monitor)が起動します．
- J2〜J5: 実験用の端子です．
- J6(DISABLE): バススイッチのOE_nをHにしてCPUとFPGAを分離します．通常は使用しないので常時openでOKです．
- J7(DBG_UART): TXだけつながったデバッグ用のUARTです．3.3V出力(5VTTLで受信可)．USBシリアル変換ケーブルは3.3V用，5V用のどちらでもOKです．
- U5(LED matrix): 「XIAO用 6x10 RGBマトリックスボード」を接続します．VccとGNDが3つ，INが2つありますが，それぞれどれかを1つづつ接続すればOKです．

## ターミナルソフト(TeraTerm)との接続
- TeraTermの設定
  - 基本的には115200bps,8N1N．
  - 改行コードは入力はAUTO, 出力はCR (おかしい場合は適宜変更)
  - 送信遅延 10ms/字, 100ms/行 (ソフトウェアによっては速すぎることあり．適宜変更)

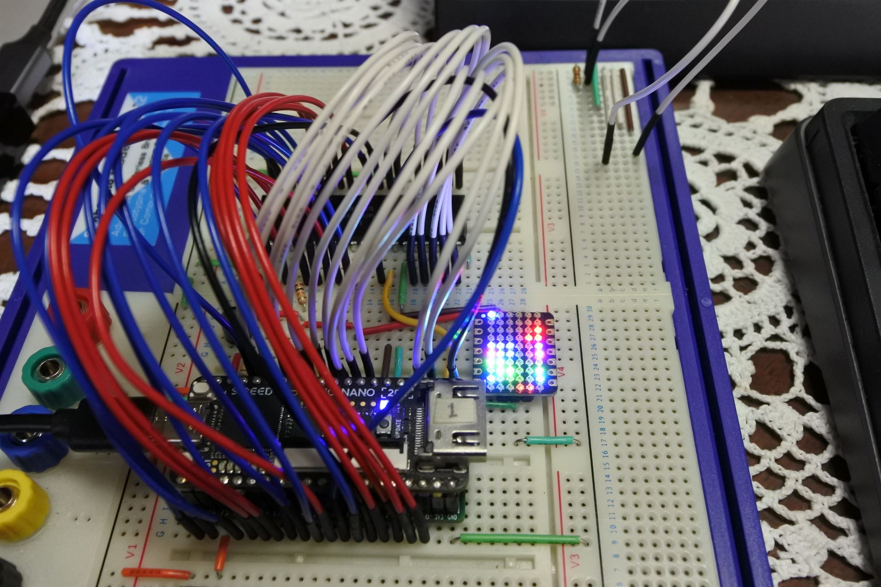
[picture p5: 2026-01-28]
images/breadboard.jpg

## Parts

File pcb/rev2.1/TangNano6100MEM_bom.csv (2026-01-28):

Reference | Value | Qty
C1 | 1uF | 1
C2,C4,C5,C6 | 0.1uF | 4
C3 | 47uF | 1
J1 | Conn_01x20 x 2 | 1
J2,J3,J4,J5 | Conn_01x20 | 4
J6 | 01x2 | 1
J7 | 01x6 | 1
LED1 | low power LED | 1
R1,R2,R4,R5,R7 | 10k | 5
R3 | 47k | 1
R6 | 1k | 1
SW1 | toggle | 1
SW2, SW3 | tactile | 1
U1 | IM6100 | 1
U2,U3,U4 | SN74CB3T3245DW | 3
U5 | WS2812B_6x10 | 1

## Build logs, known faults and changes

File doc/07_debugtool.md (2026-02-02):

# デバッグ機能
## Universal Monitor
- [Universal Monitor](https://electrelic.com/electrelic/node/1317)が既にIM6100に対応していたため，それをベースにしてControl Panel空間(CP空間)で動くように改変しました．
- CP空間ではindirect addressingによるメモリアクセスはメインメモリ空間(MM空間)へのアクセスとなるため，文字列バッファ等へのアクセスがCP空間になるようにするための修正を行いました．[tools/unimon](../tools/unimon)が修正後のソースです．
- コンテキスト(PC, AC, LINK, IF, DF)の保存と復帰を実装したので，Gで元のプログラムを続行できるはず．

### 使い方
- CPREQ スイッチを押すとCP割り込みによって起動します．PCはCP空間の0番地に保存されます．

### コマンド
- オリジナルのコマンドD, S, L, Gと、追加のコマンドR, F, Wが実装されています．
- D, S, L: MM空間に対する読み書きです．
- G: CP割り込み状態を終了してMM空間に戻ります．引数が無い場合は0番地に保存されているアドレスに復帰します．AC, LINK, IF, DFには1〜2番地に保存された値がロードされます．
- R (Register): ACを設定します．G実行時にACに代入されます．
- F (Flag and Field): フラグ(Link), IF, DF値を設定します．DFは即時，IFはG実行時に代入されます．入力&表示される値は8進数の
```
<LINK,0,IREQ> <IIF,IEFF,0> <IF><DF>
```
なので，意味があるのはMSBのLINKと，下2桁目のIF, DFです．

- W (sWitch): Switch Register (OSR命令で読まれる値)を設定します．
  - 物理的なパネルスイッチが無いので，FPGA上にレジスタを用意して実装しました．
- R, F, Wとも引数が無いときは現在の値を表示します．

### 注意事項
- CP割り込み中はHALT-FFの状態に関わらず常にRUN状態です．GしてMM空間に戻ったときに，HALT-FFが立っているためにRUNにならずにHALTしていることがよくあります．その場合はCONTスイッチを押してRUNにします．

## デバッグログ
- DBG_UARTにログを出力します．
- top.vの `define USE_ACCESSLOG を有効にすると使えます．(無効化したことがないので無効化してちゃんとビルドできるかどうかは不明)
- 詳細はtop.vを見て下さい．

### disk accessログ
- ディスクの読み書きがあった際のレジスタ値などを出力しています．

OS/8ブート時のログの例
```
時刻(ms),R/W, PC, Cmd reg., word cnt, mem addr, disk addr, drive No.
5542:RK rd,000027,000000,000400,000000,000000,000000
5558:RK rd,007671,000000,000400,000000,000007,000000
5563:RK rd,007671,001000,000400,000400,000010,000000
5567:RK rd,007671,001000,000400,001000,000011,000000
5572:RK rd,007671,001000,000400,001400,000012,000000
```

### 命令実行ログ
- HALT時やステップ実行時に最後に実行した命令やメモリアクセスを表示します．
- dbg_mode(クロックを1kHzに落としてRUN状態でも表示するモード)を実装しました．TangNanoのSW2でトグルします．
```
時刻(ms), mnem, PC, inst, read addr, data, write addr, data
8992:JMP I,007777,005776,007776,005000,000000,000000
9024:JMS I,005000,004652,007000,000000,007000,005001
9058:KCC  ,007001,006032,006032,000000,006032,000000
9078:CLA  ,007002,007200,000000,000000,000000,000000
9108:JMP I,007003,005600,007000,005001,000000,000000
9128:CLA  ,005001,007200,000000,000000,000000,000000
9148:TAD  ,005002,001253,005053,000000,000000,000000
9170:DCA0 ,005003,003140,000140,000000,000140,000000
9190:TAD  ,005004,001253,005053,000000,000000,000000
9212:DCA0 ,005005,003142,000142,000000,000142,000000
9232:TAD  ,005006,001253,005053,000000,000000,000000
9254:DCA0 ,005007,003143,000143,000000,000143,000000

```

## [tools/sample](../tools/sample)
- bootloaderやテストプログラムです．
- universal monitorのSコマンドで書いて実行します．

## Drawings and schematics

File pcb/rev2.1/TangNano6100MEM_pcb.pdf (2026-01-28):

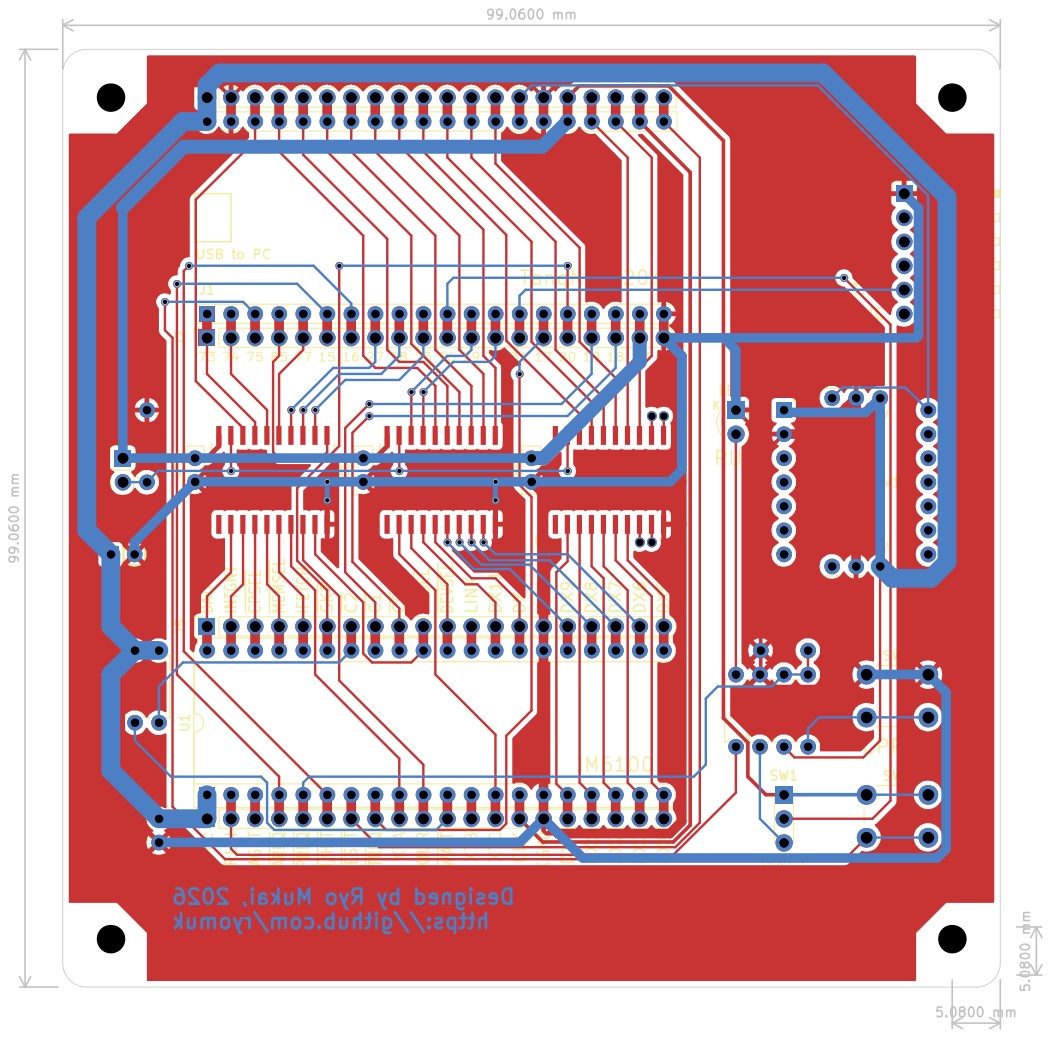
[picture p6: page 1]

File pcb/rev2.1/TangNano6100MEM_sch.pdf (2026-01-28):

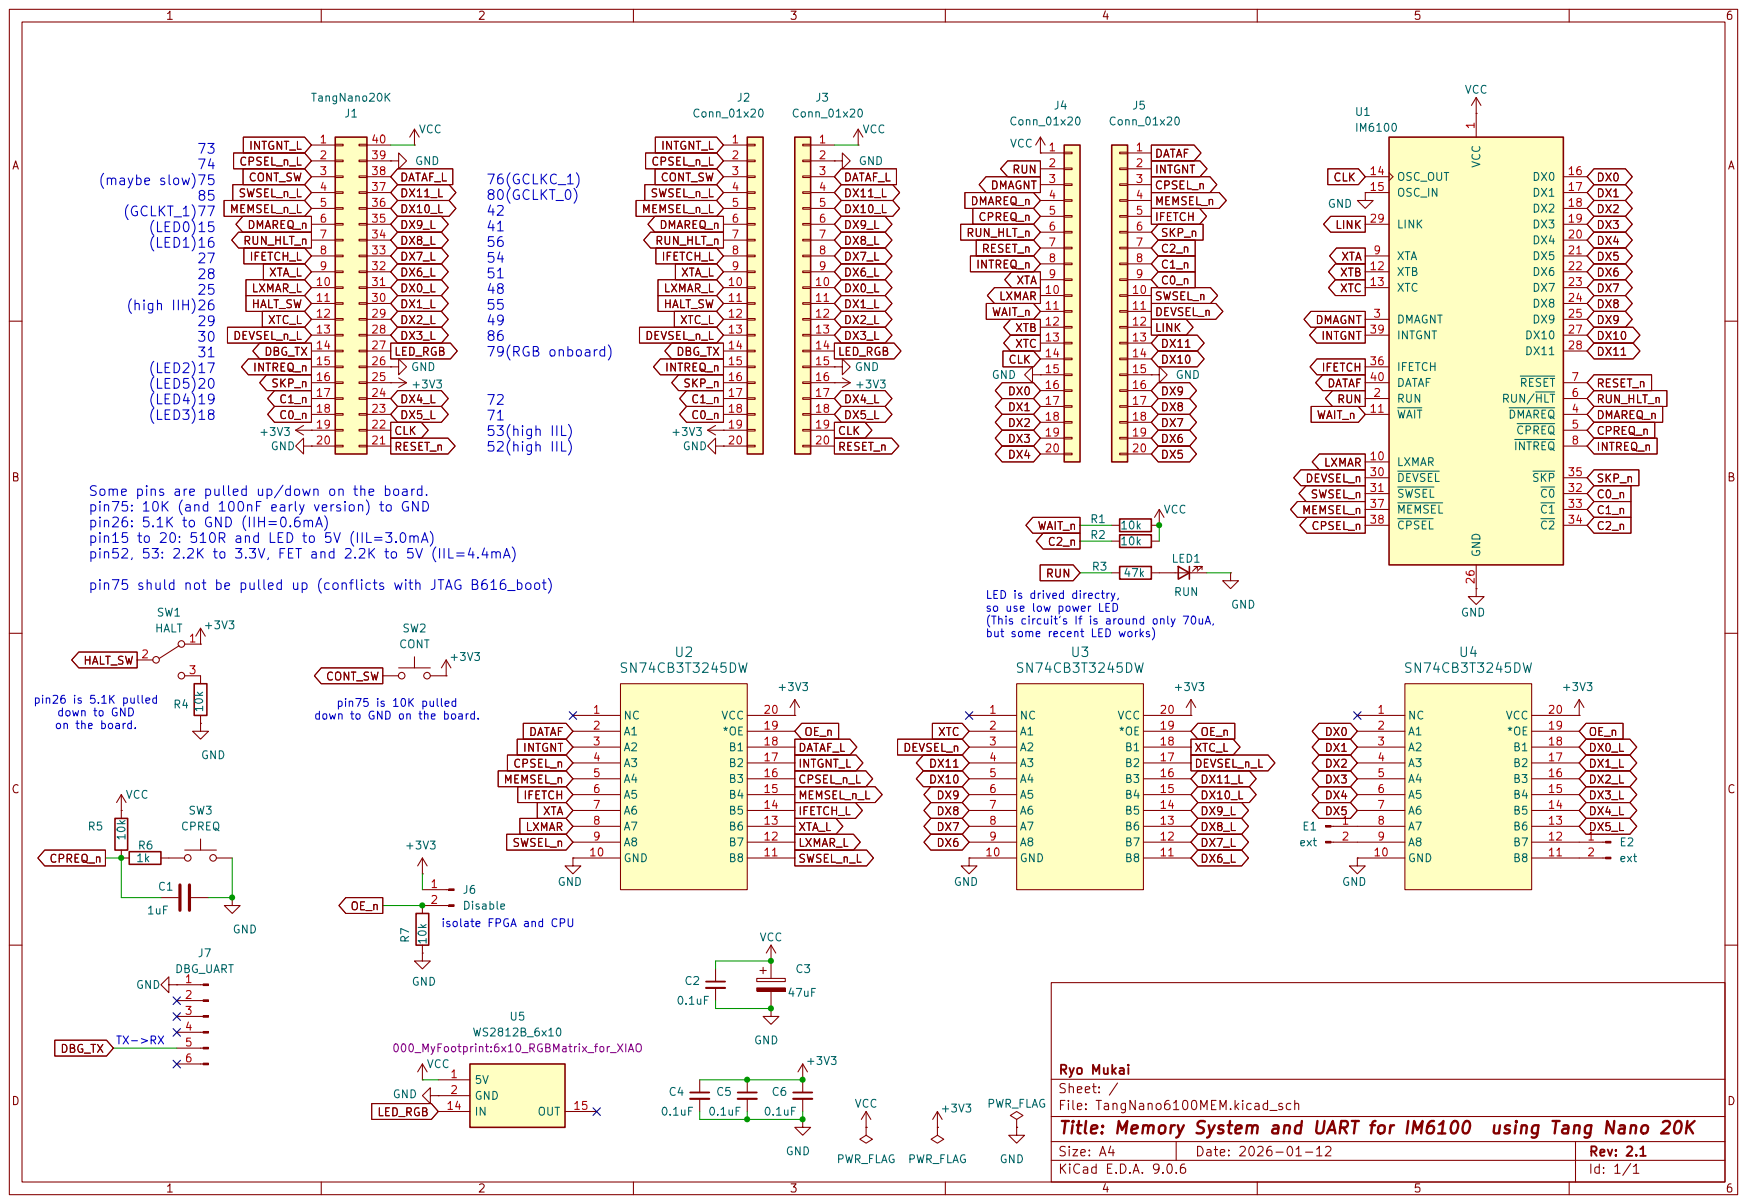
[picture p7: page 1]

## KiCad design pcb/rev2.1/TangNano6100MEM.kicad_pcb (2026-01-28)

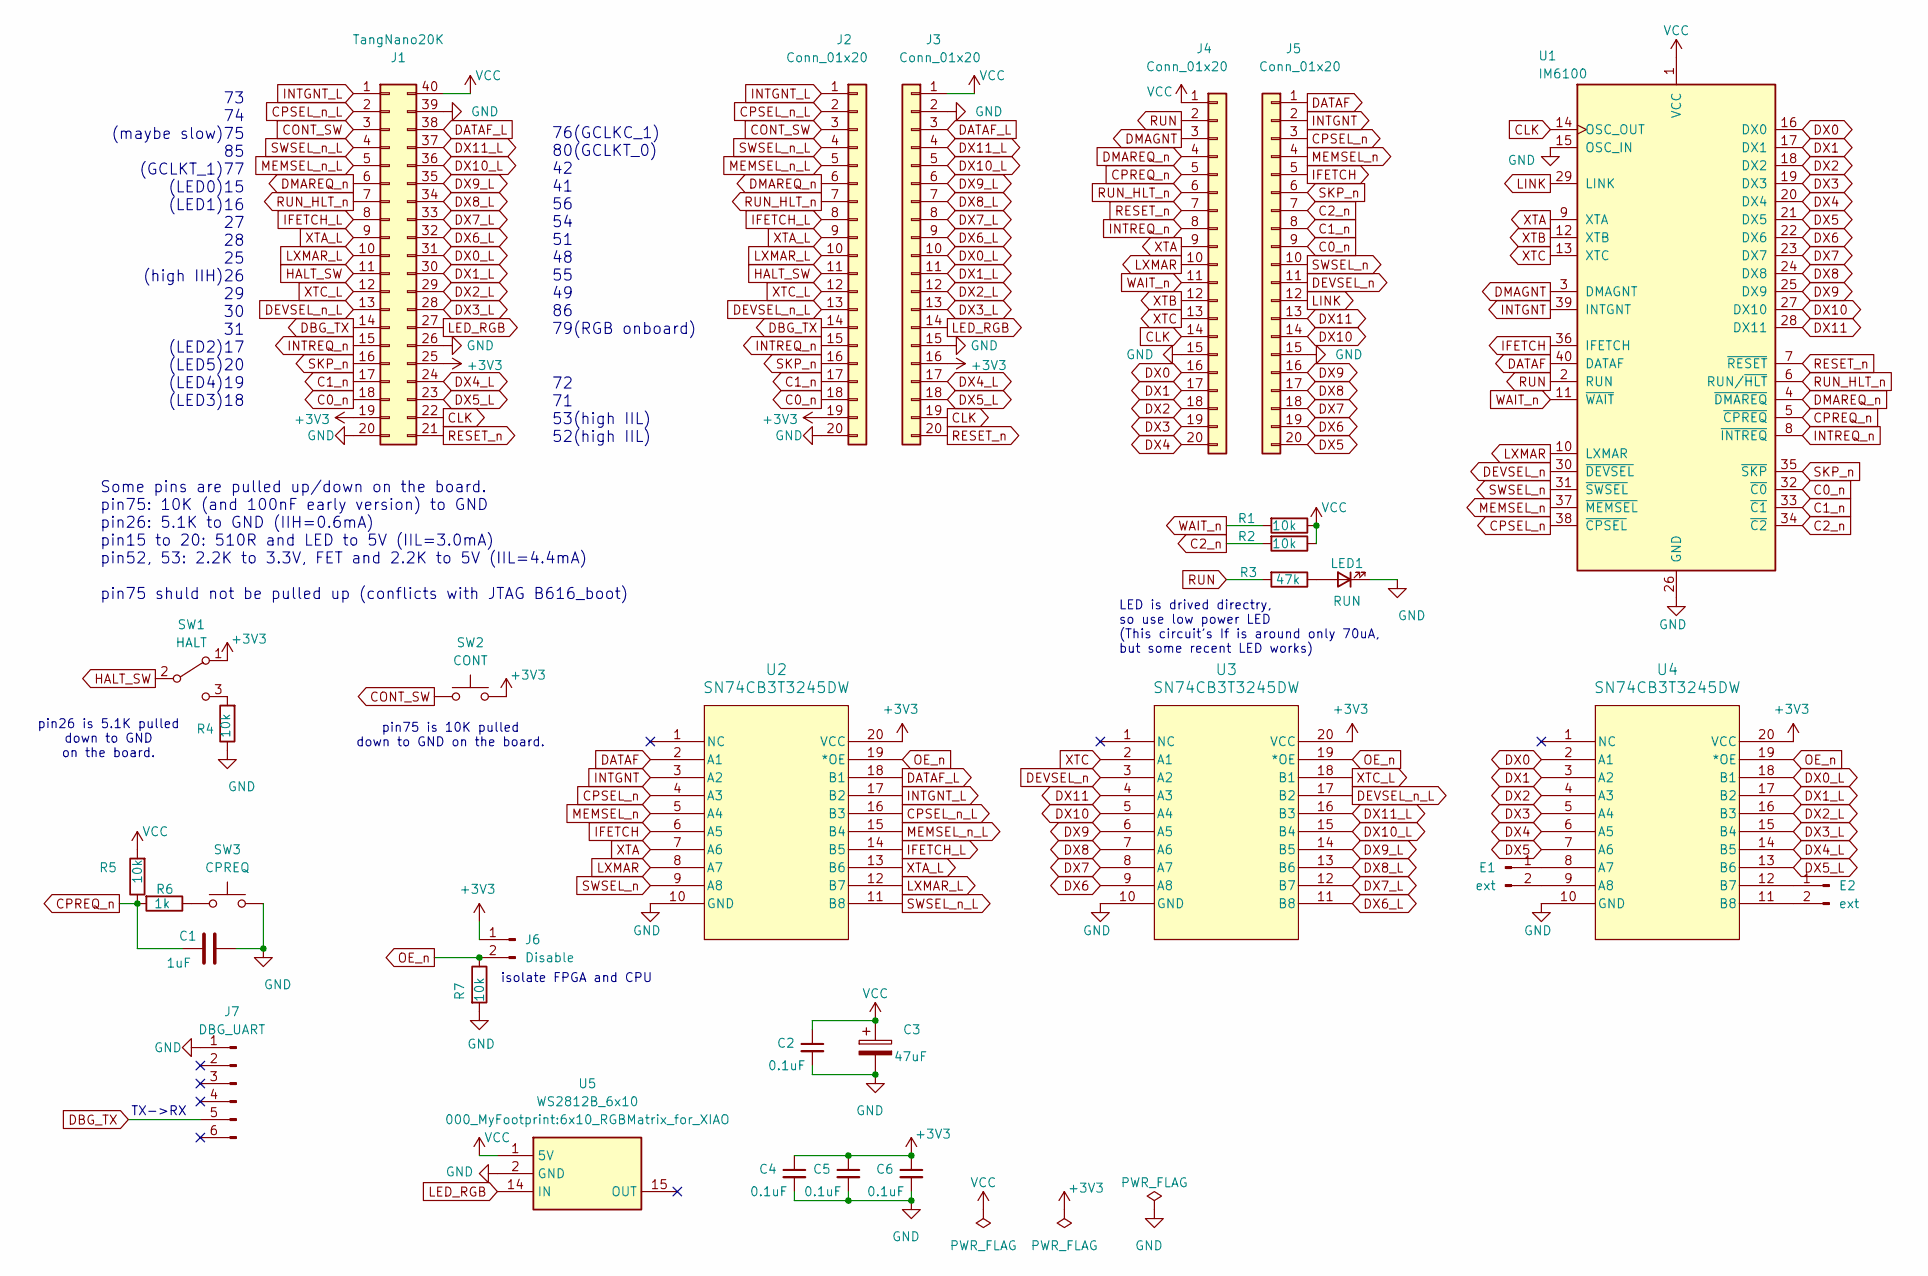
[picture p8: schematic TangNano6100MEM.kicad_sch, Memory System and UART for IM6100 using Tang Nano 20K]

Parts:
C1: 1uF; C_Disc_D4.3mm_W1.9mm_P5.00mm
C2, C4, C5, C6: 0.1uF; C_Disc_D5.0mm_W2.5mm_P2.50mm
C3: 47uF; CP_Radial_D6.3mm_P2.50mm
E1, E2: ext; TH_1x02_P1.27mm
J1: TangNano20K; DIP-40_W20.32mm800mil_Socket
J2, J3, J4, J5: Conn_01x20; PinSocket_1x20_P2.54mm_Vertical
J6: Disable; PinHeader_1x02_P2.54mm_Vertical
J7: DBG_UART; PinHeader_1x06_P2.54mm_Horizontal
LED1: RUN; LED_D3.0mm
R1, R2, R4, R5, R7: 10k; R_Axial_DIN0207_L6.3mm_D2.5mm_P7.62mm_Horizontal
R3: 47k; R_Axial_DIN0207_L6.3mm_D2.5mm_P7.62mm_Horizontal
R6: 1k; R_Axial_DIN0207_L6.3mm_D2.5mm_P7.62mm_Horizontal
SW1: HALT; SW_SPDT_Toggle
SW2: CONT; SW_PUSH_6mm_H4.3mm
SW3: CPREQ; SW_PUSH_6mm_H4.3mm
U1: IM6100; DIP-40_W15.24mm_Socket
U2, U3, U4: SN74CB3T3245DW; DW20
U5: WS2812B_6x10; 6x10_RGBMatrix_for_XIAO

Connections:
+3V3: C4.1, C5.1, C6.1, J1.19, J1.25, J2.19, J3.16, J6.1, SW1.1 (A), SW2.1, U2.20 (VCC), U3.20 (VCC), U4.20 (VCC)
C0_n: J1.18, J2.18, J5.9, U1.32 (~C0)
C1_n: J1.17, J2.17, J5.8, U1.33 (~C1)
C2_n: J5.7, R2.2, U1.34 (~C2)
CLK: J1.22, J3.19, J4.14, U1.14 (OSC_OUT)
CONT_SW: J1.3, J2.3, SW2.2
CPREQ_n: C1.1, J4.5, R5.1, R6.2, U1.5 (~CPREQ)
CPSEL_n: J5.3, U1.38 (~CPSEL), U2.4 (A3)
CPSEL_n_L: J1.2, J2.2, U2.16 (B3)
DATAF: J5.1, U1.40 (DATAF), U2.2 (A1)
DATAF_L: J1.38, J3.3, U2.18 (B1)
DBG_TX: J1.14, J2.14, J7.5
DEVSEL_n: J5.11, U1.30 (~DEVSEL), U3.3 (A2)
DEVSEL_n_L: J1.13, J2.13, U3.17 (B2)
DMAGNT: J4.3, U1.3 (DMAGNT)
DMAREQ_n: J1.6, J2.6, J4.4, U1.4 (~DMAREQ)
DX0: J4.16, U1.16 (DX0), U4.2 (A1)
DX0_L: J1.31, J3.10, U4.18 (B1)
DX1: J4.17, U1.17 (DX1), U4.3 (A2)
DX1_L: J1.30, J3.11, U4.17 (B2)
DX2: J4.18, U1.18 (DX2), U4.4 (A3)
DX2_L: J1.29, J3.12, U4.16 (B3)
DX3: J4.19, U1.19 (DX3), U4.5 (A4)
DX3_L: J1.28, J3.13, U4.15 (B4)
DX4: J4.20, U1.20 (DX4), U4.6 (A5)
DX4_L: J1.24, J3.17, U4.14 (B5)
DX5: J5.20, U1.21 (DX5), U4.7 (A6)
DX5_L: J1.23, J3.18, U4.13 (B6)
DX6: J5.19, U1.22 (DX6), U3.9 (A8)
DX6_L: J1.32, J3.9, U3.11 (B8)
DX7: J5.18, U1.23 (DX7), U3.8 (A7)
DX7_L: J1.33, J3.8, U3.12 (B7)
DX8: J5.17, U1.24 (DX8), U3.7 (A6)
DX8_L: J1.34, J3.7, U3.13 (B6)
DX9: J5.16, U1.25 (DX9), U3.6 (A5)
DX9_L: J1.35, J3.6, U3.14 (B5)
DX10: J5.14, U1.27 (DX10), U3.5 (A4)
DX10_L: J1.36, J3.5, U3.15 (B4)
DX11: J5.13, U1.28 (DX11), U3.4 (A3)
DX11_L: J1.37, J3.4, U3.16 (B3)
GND: C1.2, C2.2, C3.2, C4.2, C5.2, C6.2, J1.20, J1.26, J1.39, J2.20, J3.2, J3.15, J4.15, J5.15, J7.1, LED1.1 (K), R4.1, R7.2, SW3.1, U1.15 (OSC_IN), U1.26 (GND), U2.10 (GND), U3.10 (GND), U4.10 (GND), U5.2 (GND)
HALT_SW: J1.11, J2.11, SW1.2 (B)
IFETCH: J5.5, U1.36 (IFETCH), U2.6 (A5)
IFETCH_L: J1.8, J2.8, U2.14 (B5)
INTGNT: J5.2, U1.39 (INTGNT), U2.3 (A2)
INTGNT_L: J1.1, J2.1, U2.17 (B2)
INTREQ_n: J1.15, J2.15, J4.8, U1.8 (~INTREQ)
LED_RGB: J1.27, J3.14, U5.14 (IN)
LINK: J5.12, U1.29 (LINK)
LXMAR: J4.10, U1.10 (LXMAR), U2.8 (A7)
LXMAR_L: J1.10, J2.10, U2.12 (B7)
MEMSEL_n: J5.4, U1.37 (~MEMSEL), U2.5 (A4)
MEMSEL_n_L: J1.5, J2.5, U2.15 (B4)
unnamed: E1.1, U4.8 (A7)
unnamed: E1.2, U4.9 (A8)
unnamed: E2.1, U4.12 (B7)
unnamed: E2.2, U4.11 (B8)
unnamed: LED1.2 (A), R3.1
unnamed: R6.1, SW3.2
unnamed: R4.2, SW1.3 (C)
OE_n: J6.2, R7.1, U2.19 (*OE), U3.19 (*OE), U4.19 (*OE)
RESET_n: J1.21, J3.20, J4.7, U1.7 (~RESET)
RUN: J4.2, R3.2, U1.2 (RUN)
RUN_HLT_n: J1.7, J2.7, J4.6, U1.6 (RUN/~HLT)
SKP_n: J1.16, J2.16, J5.6, U1.35 (~SKP)
SWSEL_n: J5.10, U1.31 (~SWSEL), U2.9 (A8)
SWSEL_n_L: J1.4, J2.4, U2.11 (B8)
VCC: C2.1, C3.1, J1.40, J3.1, J4.1, R1.1, R2.1, R5.2, U1.1 (VCC), U5.1 (5V)
WAIT_n: J4.11, R1.2, U1.11 (~WAIT)
XTA: J4.9, U1.9 (XTA), U2.7 (A6)
XTA_L: J1.9, J2.9, U2.13 (B6)
XTB: J4.12, U1.12 (XTB)
XTC: J4.13, U1.13 (XTC), U3.2 (A1)
XTC_L: J1.12, J2.12, U3.18 (B1)

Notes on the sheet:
TX->RX
72 71 53(high IIL) 52(high IIL)
73 74 (maybe slow)75 85 (GCLKT_1)77 (LED0)15 (LED1)16 27 28 25 (high IIH)26 29 30 31 (LED2)17 (LED5)20 (LED4)19 (LED3)18
76(GCLKC_1) 80(GCLKT_0) 42 41 56 54 51 48 55 49 86 79(RGB onboard)
Some pins are pulled up/down on the board. pin75: 10K (and 100nF early version) to GND pin26: 5.1K to GND (IIH=0.6mA) pin15 to 20: 510R and LED to 5V (IIL=3.0mA) pin52, 53: 2.2K to 3.3V, FET and 2.2K to 5V (IIL=4.4mA) pin75 shuld not be pulled up (conflicts with JTAG B616_boot)
isolate FPGA and CPU
pin26 is 5.1K pulled down to GND on the board.
pin75 is 10K pulled down to GND on the board.
LED is drived directry, so use low power LED (This circuit's If is around only 70uA, but some recent LED works)

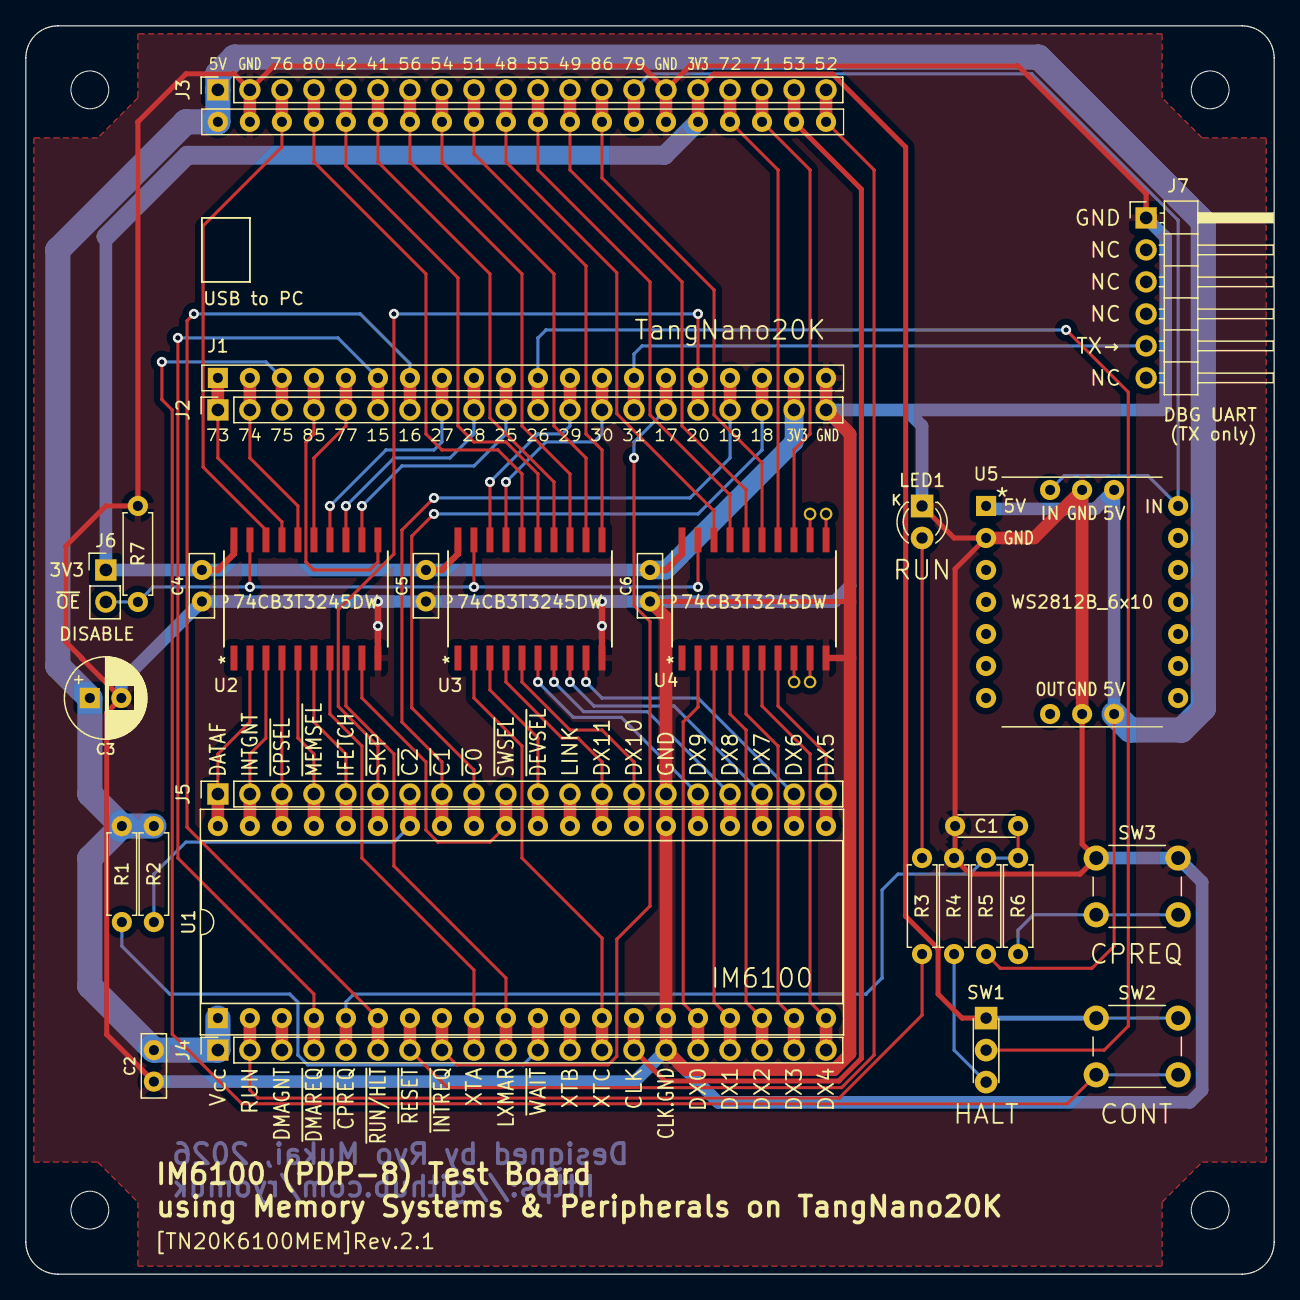
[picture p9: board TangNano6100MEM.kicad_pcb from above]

Board: 2 copper layers, 99.1 x 99.1 mm, 31 parts (0 on the bottom side), 74 nets.

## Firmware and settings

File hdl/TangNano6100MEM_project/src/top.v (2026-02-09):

//---------------------------------------------------------------------------
// TangNano6100MEM
// Memory System and Peripherals for IM6100 using Tang Nano 20K
//
// version 20260206
//
// by Ryo Mukai
//
// 2026/01/28: - initial version for PCB rev.2.1
//             - implemented features are
//                 - 32KW extended main memory
//                 - 4KW Control Panel memory
//                 - TTY (UART)
//                 - interrupt (TTY, clock)
//                 - RK8E/RK05 disk emulator
//                 - functions for debug
//                   - HALT, CONT(RUN/HLT) switch
//                   - 6x10 matrix LED
//                   - debug log UART (disk access, etc.)
//                 - Universal Monitor on CP Memory
// 2026/01/29: - bug fixed (done flag of RK status register)
//             - dbg_mode (slow clock and full instruction log) implemented
// 2026/02/01: - paper tape emulator implimented
// 2026/02/02: - bug fixed (clear REG_IF, DF, IB on INTGNT)
// 2026/02/06: - bug fixed (disable IF<=IB in CP space)
//---------------------------------------------------------------------------

`define USE_DBGLOG   // output debug information to DBG_TX

module top
  (
   input	sys_clk27, // 27MHz system clock (Tang Nano 20K)
   input	uart_rx,
   output	uart_tx,
   
   output	sd_clk,
   output	sd_mosi, 
   input	sd_miso,
   output	sd_cs_n,

   input	sw1,
   input	sw2,
   input	HALT_SW,
   input	CONT_SW,

   output	CLK,
   output reg	RESET_n,
   
   inout [11:0]	DX,
//   input	DMAGNT,
   input	INTGNT,

   input	IFETCH,
   input	DATAF,

   input	LXMAR,
   input	MEMSEL_n,
   input	DEVSEL_n,
   input	CPSEL_n,
   input	SWSEL_n,

   output	DMAREQ_n,
   output	RUN_HLT_n,
   output	INTREQ_n,

//   input	LINK,
   input	XTA,
   input	XTC,

   output	SKP_n,
   output	C0_n,
   output	C1_n,
//   output	C2_n,

   output	LED_RGB,
   output	DBG_TX
    );
  parameter H = 1'b1;
  parameter L = 1'b0;
  
  parameter SYS_CLK_FRQ  = 27_000_000; //Hz
  wire	    sys_clk = sys_clk27; // 27MHz system clock (Tang Nano 20K)
    
  // CPU_CLK_RATIO = SYS_CLK_FRQ / CPU_CLK_FRQ
//  parameter CPU_CLK_RATIO =  4;   // 6.75MHz (some IM6100A works @5V)
//  parameter CPU_CLK_RATIO =  5;   // 5.4 MHz (most IM6100A works @5V)
//  parameter CPU_CLK_RATIO =  6;   // 4.5 MHz
//  parameter CPU_CLK_RATIO =  7;   // 3.857MHz
  parameter CPU_CLK_RATIO =  8;   // 3.375MHz (IM6100A safe driving @5V)
//  parameter CPU_CLK_RATIO =  9;   // 3.0MHz  (IM6100-1 @5V)
//  parameter CPU_CLK_RATIO = 11;   // 2.45MHz (IM6100 @5V)
//  parameter CPU_CLK_RATIO = 27;   // 1.0 MHz

  // for debug with full instruction trace log
  parameter DBG_CLK_RATIO = 27000; // 1KHz
  
  parameter CPU_CLK_FRQ = SYS_CLK_FRQ / CPU_CLK_RATIO;

    parameter	 UART_BPS    =     115200; //Hz
//  parameter	 UART_BPS    =       9600; //Hz

  reg [11:0]	 mem[32767:0];   // 32KW Main Memory
  reg [11:0]	 mem_cp[4095:0]; //  4KW Control Panel Memory
  reg [11:0]	 address;
  reg [2:0]	 field;
  wire [14:0]    ext_address = {field, address};

// USB UART
  reg [7:0]	 tx_data;
  reg		 tx_send;
  wire		 tx_ready;
  wire [7:0]	 rx_data;
  wire		 rx_data_ready;
  reg		 rx_clear;
  
//---------------------------------------------------------------------------
// OP codes
//---------------------------------------------------------------------------
  parameter	 OP_AND = 3'o0;
  parameter	 OP_TAD = 3'o1;
  parameter	 OP_ISZ = 3'o2;
  parameter	 OP_DCA = 3'o3;
  parameter	 OP_JMS = 3'o4;
  parameter	 OP_JMP = 3'o5;
  parameter	 OP_IOT = 3'o6;

//---------------------------------------------------------------------------
// IOT Device Instructions/Addresses
//---------------------------------------------------------------------------
  // Processor
  parameter IOT_SKON  = 12'o6000; // Skip on interrupt on, Interrupt disabled
  parameter IOT_ION   = 12'o6001; // Interrupt enabled
  parameter IOT_IOF   = 12'o6002; // Interrupt disabled
  parameter IOT_CAF   = 12'o6007; // Clear all flags, Interrupt disabled
  
  // Paper Tape Reader (PR)
  parameter IOT_RPE   = 12'o6010; // Set/Clear IE (not implemented yet)
  parameter IOT_RSF   = 12'o6011; // Reader Skip if Flag
  parameter IOT_RRB   = 12'o6012; // Read Reader Buffer
  parameter IOT_RFC   = 12'o6014; // Reader Fetch Character
  parameter IOT_RFCRRB = 12'o6016; // Read Buffer and fetch new char

  // TTY input (Keyboard, KB)
  parameter IOT_KSF   = 12'o6031; // Skip on KB Flag
  parameter IOT_KCC   = 12'o6032; // Clear KB Flag and AC, Advance reader
  parameter IOT_KRS   = 12'o6034; // Read KB buffer static
  parameter IOT_KIE   = 12'o6035; // Set/Clear IE (not implemented yet)
  parameter IOT_KRB   = 12'o6036; // Read KB, Clear flag

  // TTY output (Teleprinter, TP)
  parameter IOT_TFL   = 12'o6040; // Set TP flag
  parameter IOT_TSF   = 12'o6041; // Skip on TP flag
  parameter IOT_TCF   = 12'o6042; // Clear TP flag
  parameter IOT_TPC   = 12'o6044; // Load TP and Print
  parameter IOT_TLS   = 12'o6046; // Load TP sequence

  // Extended Memory
  parameter IOT_GTF   = 12'o6004;
  parameter IOT_RTF   = 12'o6005;
  parameter IOT_N_CDF =  9'o62_1; // 62N1
  parameter IOT_N_CIF =  9'o62_2; // 62N2
  parameter IOT_N_CDI =  9'o62_3; // 62N3
  parameter IOT_RDF   = 12'o6214;
  parameter IOT_RIF   = 12'o6224;
  parameter IOT_RIB   = 12'o6234;
  parameter IOT_RMF   = 12'o6244;
  parameter IOT_LIF   = 12'o6254;
    
  // user's device
  parameter IOT_SWR   = 12'o6301; // Load SW register

  // RK disk 67X[1-6] (X=4)
  parameter IOT_DSKP  = 12'o6741;
  parameter IOT_DCLR  = 12'o6742;
  parameter IOT_DLAG  = 12'o6743;
  parameter IOT_DLCA  = 12'o6744;
  parameter IOT_DRST  = 12'o6745;
  parameter IOT_DLDC  = 12'o6746;

  

//---------------------------------------------------------------------------
// Initial Memory Data
//---------------------------------------------------------------------------
`include "mem.v"
`include "mem_cp.v"
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

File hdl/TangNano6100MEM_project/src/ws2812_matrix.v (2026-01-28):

// WS2812B RGB LED matrix array driver
// 2026/01/14
// by Ryo Mukai

// WIDTHxHEIGHT is 6x10, 10x6, 12x10, 20x6

module ws2812_matrix
  #(
    parameter CLK_FRQ = 27_000_000,
    parameter BRIGHTNESS_R = 8'h02,
    parameter BRIGHTNESS_G = 8'h02,
    parameter BRIGHTNESS_B = 8'h02,
    parameter WIDTH = 6,
    parameter HEIGHT = 10,
    parameter LEDS = WIDTH * HEIGHT
    )
  (
   input	    clk,
   output	    sout,
   input [LEDS-1:0] r,
   input [LEDS-1:0] g,
   input [LEDS-1:0] b
   );
  
  // mapping from bitmap to 6x10 matrix is straightforward
  //MSB-> 0  1  2  3  4  5
  //      6  8  9 10 11 12
  //      ...
  //     54 55 56 57 58 59
  function [(60*8)-1:0] bmp2stream_6x10(input [59:0] x, [7:0] br);
     bmp2stream_6x10[(60*8)-1:0]
       = {
	  x[ 0] ? br: 8'h00,
	  x[ 1] ? br: 8'h00,
	  x[ 2] ? br: 8'h00,
	  x[ 3] ? br: 8'h00,
	  x[ 4] ? br: 8'h00,
	  x[ 5] ? br: 8'h00,
	  x[ 6] ? br: 8'h00,
	  x[ 7] ? br: 8'h00,
	  x[ 8] ? br: 8'h00,
	  x[ 9] ? br: 8'h00,
	  x[10] ? br: 8'h00,
	  x[11] ? br: 8'h00,
	  x[12] ? br: 8'h00,
	  x[13] ? br: 8'h00,
	  x[14] ? br: 8'h00,
	  x[15] ? br: 8'h00,
	  x[16] ? br: 8'h00,
	  x[17] ? br: 8'h00,
	  x[18] ? br: 8'h00,
	  x[19] ? br: 8'h00,
	  x[20] ? br: 8'h00,
	  x[21] ? br: 8'h00,
	  x[22] ? br: 8'h00,
	  x[23] ? br: 8'h00,
	  x[24] ? br: 8'h00,
	  x[25] ? br: 8'h00,
	  x[26] ? br: 8'h00,
	  x[27] ? br: 8'h00,
	  x[28] ? br: 8'h00,
	  x[29] ? br: 8'h00,
	  x[30] ? br: 8'h00,
	  x[31] ? br: 8'h00,
	  x[32] ? br: 8'h00,
	  x[33] ? br: 8'h00,
	  x[34] ? br: 8'h00,
	  x[35] ? br: 8'h00,
	  x[36] ? br: 8'h00,
	  x[37] ? br: 8'h00,
	  x[38] ? br: 8'h00,
	  x[39] ? br: 8'h00,
	  x[40] ? br: 8'h00,
	  x[41] ? br: 8'h00,
	  x[42] ? br: 8'h00,
	  x[43] ? br: 8'h00,
	  x[44] ? br: 8'h00,
	  x[45] ? br: 8'h00,
	  x[46] ? br: 8'h00,
	  x[47] ? br: 8'h00,
	  x[48] ? br: 8'h00,
	  x[49] ? br: 8'h00,
	  x[50] ? br: 8'h00,
	  x[51] ? br: 8'h00,
	  x[52] ? br: 8'h00,
	  x[53] ? br: 8'h00,
	  x[54] ? br: 8'h00,
	  x[55] ? br: 8'h00,
	  x[56] ? br: 8'h00,
	  x[57] ? br: 8'h00,
	  x[58] ? br: 8'h00,
	  x[59] ? br: 8'h00
};
  endfunction

  // mapping from bitmap to 10x6 matrix
  //         0  1 ...  9
  //        ..
  //        40 41 ... 49
  // MSB -> 50 51 ... 59
  //
  function [(60*8)-1:0] bmp2stream_10x6(input [59:0] x, [7:0] br);
     bmp2stream_10x6[(60*8)-1:0]
       = {
	  x[50] ? br: 8'h00,
	  x[40] ? br: 8'h00,
	  x[30] ? br: 8'h00,
	  x[20] ? br: 8'h00,
	  x[10] ? br: 8'h00,
	  x[ 0] ? br: 8'h00,
//
	  x[51] ? br: 8'h00,
	  x[41] ? br: 8'h00,
	  x[31] ? br: 8'h00,
	  x[21] ? br: 8'h00,
	  x[11] ? br: 8'h00,
	  x[ 1] ? br: 8'h00,
//
	  x[52] ? br: 8'h00,
	  x[42] ? br: 8'h00,
	  x[32] ? br: 8'h00,
	  x[22] ? br: 8'h00,
	  x[12] ? br: 8'h00,
	  x[ 2] ? br: 8'h00,
//
	  x[53] ? br: 8'h00,
	  x[43] ? br: 8'h00,
	  x[33] ? br: 8'h00,
	  x[23] ? br: 8'h00,
	  x[13] ? br: 8'h00,
	  x[ 3] ? br: 8'h00,
//
	  x[54] ? br: 8'h00,
	  x[44] ? br: 8'h00,
	  x[34] ? br: 8'h00,
	  x[24] ? br: 8'h00,
	  x[14] ? br: 8'h00,
	  x[ 4] ? br: 8'h00,
//
	  x[55] ? br: 8'h00,
	  x[45] ? br: 8'h00,
	  x[35] ? br: 8'h00,
	  x[25] ? br: 8'h00,
	  x[15] ? br: 8'h00,
	  x[ 5] ? br: 8'h00,
//
	  x[56] ? br: 8'h00,
	  x[46] ? br: 8'h00,
	  x[36] ? br: 8'h00,
	  x[26] ? br: 8'h00,
	  x[16] ? br: 8'h00,
	  x[ 6] ? br: 8'h00,
//
	  x[57] ? br: 8'h00,
	  x[47] ? br: 8'h00,
	  x[37] ? br: 8'h00,
	  x[27] ? br: 8'h00,
	  x[17] ? br: 8'h00,
	  x[ 7] ? br: 8'h00,
//
	  x[58] ? br: 8'h00,
	  x[48] ? br: 8'h00,
	  x[38] ? br: 8'h00,
	  x[28] ? br: 8'h00,
	  x[18] ? br: 8'h00,
	  x[ 8] ? br: 8'h00,
//
	  x[59] ? br: 8'h00,
	  x[49] ? br: 8'h00,
	  x[39] ? br: 8'h00,
	  x[29] ? br: 8'h00,
	  x[19] ? br: 8'h00,
	  x[ 9] ? br: 8'h00
};
  endfunction
     
  // mapping from bitmap to 20x6 matrix
  //         0   1 ...   9  10 ...  19
  //        20  21
  //        40  41
  //        60  61
  //        80  81      89  90 ...  99
  // MSB-> 100 101 ... 109 110 ... 119
  // 
  //   
  function [120*8-1:0] bmp2stream_20x6(input [119:0] x, [7:0] br);
     bmp2stream_20x6[120*8-1:0]
       = {
	  x[100] ? br: 8'h00,
	  x[ 80] ? br: 8'h00,
	  x[ 60] ? br: 8'h00,
	  x[ 40] ? br: 8'h00,
	  x[ 20] ? br: 8'h00,
	  x[  0] ? br: 8'h00,
//
	  x[101] ? br: 8'h00,
	  x[ 81] ? br: 8'h00,
	  x[ 61] ? br: 8'h00,
	  x[ 41] ? br: 8'h00,
	  x[ 21] ? br: 8'h00,
	  x[  1] ? br: 8'h00,
//
	  x[102] ? br: 8'h00,
	  x[ 82] ? br: 8'h00,
	  x[ 62] ? br: 8'h00,
	  x[ 42] ? br: 8'h00,
	  x[ 22] ? br: 8'h00,
	  x[  2] ? br: 8'h00,
//
	  x[103] ? br: 8'h00,
	  x[ 83] ? br: 8'h00,
	  x[ 63] ? br: 8'h00,
	  x[ 43] ? br: 8'h00,
	  x[ 23] ? br: 8'h00,
	  x[  3] ? br: 8'h00,
//
	  x[104] ? br: 8'h00,
	  x[ 84] ? br: 8'h00,
	  x[ 64] ? br: 8'h00,
	  x[ 44] ? br: 8'h00,
	  x[ 24] ? br: 8'h00,
	  x[  4] ? br: 8'h00,
//
	  x[105] ? br: 8'h00,
	  x[ 85] ? br: 8'h00,
	  x[ 65] ? br: 8'h00,
	  x[ 45] ? br: 8'h00,
	  x[ 25] ? br: 8'h00,
	  x[  5] ? br: 8'h00,
//
	  x[106] ? br: 8'h00,
	  x[ 86] ? br: 8'h00,
	  x[ 66] ? br: 8'h00,
	  x[ 46] ? br: 8'h00,
	  x[ 26] ? br: 8'h00,
	  x[  6] ? br: 8'h00,
//
	  x[107] ? br: 8'h00,
	  x[ 87] ? br: 8'h00,
	  x[ 67] ? br: 8'h00,
	  x[ 47] ? br: 8'h00,
	  x[ 27] ? br: 8'h00,
	  x[  7] ? br: 8'h00,
//
	  x[108] ? br: 8'h00,
	  x[ 88] ? br: 8'h00,
	  x[ 68] ? br: 8'h00,
	  x[ 48] ? br: 8'h00,
	  x[ 28] ? br: 8'h00,
	  x[  8] ? br: 8'h00,
//
	  x[109] ? br: 8'h00,
	  x[ 89] ? br: 8'h00,
	  x[ 69] ? br: 8'h00,
	  x[ 49] ? br: 8'h00,
	  x[ 29] ? br: 8'h00,
	  x[  9] ? br: 8'h00,
//
	  x[110] ? br: 8'h00,
	  x[ 90] ? br: 8'h00,
	  x[ 70] ? br: 8'h00,
	  x[ 50] ? br: 8'h00,
	  x[ 30] ? br: 8'h00,
	  x[ 10] ? br: 8'h00,
//
	  x[111] ? br: 8'h00,
	  x[ 91] ? br: 8'h00,
	  x[ 71] ? br: 8'h00,
	  x[ 51] ? br: 8'h00,
	  x[ 31] ? br: 8'h00,
	  x[ 11] ? br: 8'h00,
//
	  x[112] ? br: 8'h00,
	  x[ 92] ? br: 8'h00,
	  x[ 72] ? br: 8'h00,
	  x[ 52] ? br: 8'h00,
	  x[ 32] ? br: 8'h00,
	  x[ 12] ? br: 8'h00,
//
	  x[113] ? br: 8'h00,
	  x[ 93] ? br: 8'h00,
	  x[ 73] ? br: 8'h00,
	  x[ 53] ? br: 8'h00,
	  x[ 33] ? br: 8'h00,
	  x[ 13] ? br: 8'h00,
//
	  x[114] ? br: 8'h00,
	  x[ 94] ? br: 8'h00,
	  x[ 74] ? br: 8'h00,
	  x[ 54] ? br: 8'h00,
	  x[ 34] ? br: 8'h00,
	  x[ 14] ? br: 8'h00,
//
	  x[115] ? br: 8'h00,
	  x[ 95] ? br: 8'h00,
	  x[ 75] ? br: 8'h00,
	  x[ 55] ? br: 8'h00,
	  x[ 35] ? br: 8'h00,
	  x[ 15] ? br: 8'h00,
//
	  x[116] ? br: 8'h00,
	  x[ 96] ? br: 8'h00,
	  x[ 76] ? br: 8'h00,
	  x[ 56] ? br: 8'h00,
	  x[ 36] ? br: 8'h00,
	  x[ 16] ? br: 8'h00,
//
	  x[117] ? br: 8'h00,
	  x[ 97] ? br: 8'h00,
	  x[ 77] ? br: 8'h00,
	  x[ 57] ? br: 8'h00,
	  x[ 37] ? br: 8'h00,
	  x[ 17] ? br: 8'h00,
//
	  x[118] ? br: 8'h00,
	  x[ 98] ? br: 8'h00,
	  x[ 78] ? br: 8'h00,
	  x[ 58] ? br: 8'h00,
	  x[ 38] ? br: 8'h00,
	  x[ 18] ? br: 8'h00,
//
	  x[119] ? br: 8'h00,
	  x[ 99] ? br: 8'h00,
	  x[ 79] ? br: 8'h00,
	  x[ 59] ? br: 8'h00,
	  x[ 39] ? br: 8'h00,
	  x[ 19] ? br: 8'h00
};
  endfunction
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
